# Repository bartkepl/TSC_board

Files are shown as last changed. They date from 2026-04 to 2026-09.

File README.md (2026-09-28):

# TSC (TimeStamp Counter)
TimeStamp Counter board, addon board to UCB_board 
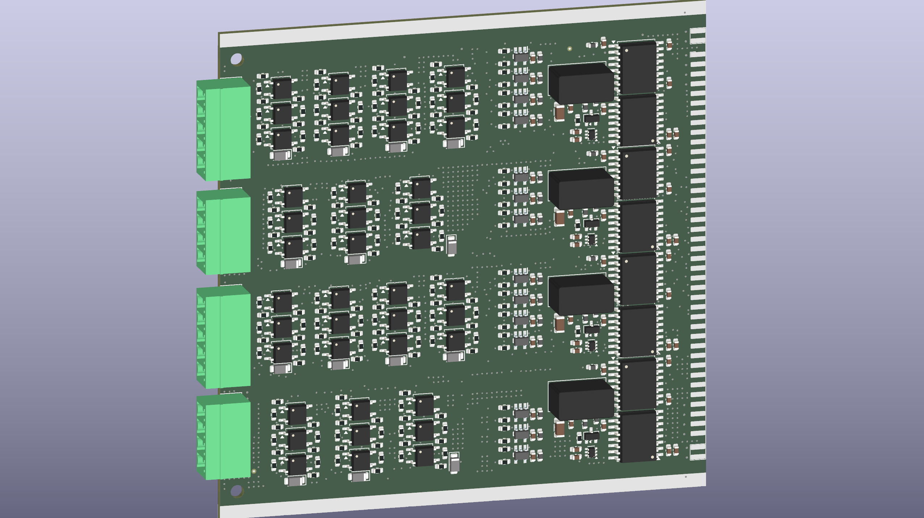
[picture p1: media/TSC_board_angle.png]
Time Stamp Counter board


| Top | Bottom |
|---|---|
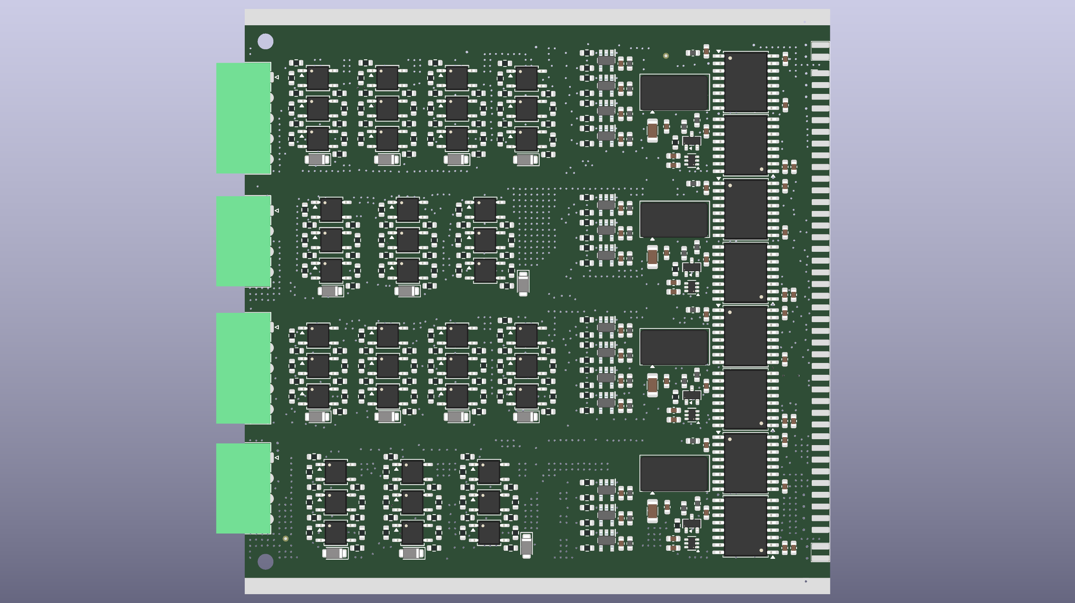
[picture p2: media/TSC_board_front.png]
Top
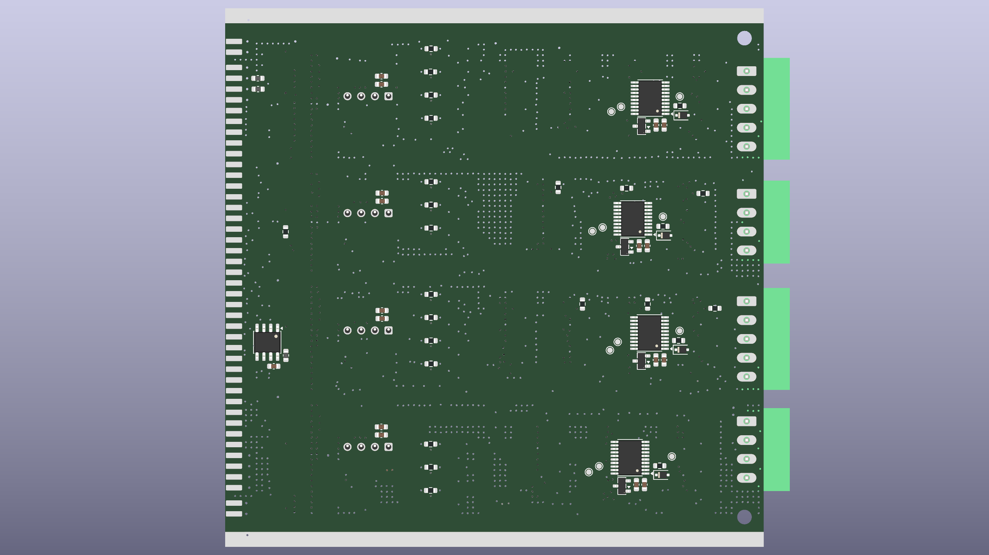
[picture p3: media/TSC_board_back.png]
Bottom
|  |  |

---
## Status: ready for prototype order

- Schematic and PCB layout done (4-layer, 100 × 100 mm), production files generated.
- Design review completed; DRC/ERC clean (remaining items reviewed and excluded as by-design).
- Hand assembly (2 fiducials on F.Cu for stencil alignment); LM4040 references (U15/U32/U46/U60) are DNP in this revision.

Production outputs: [schematic PDF](prod/sch/TSC_board.pdf) · [PCB PDF](prod/pcb/TSC_board.pdf) · [interactive BOM](prod/ibom/TSC_board_ibom.html) · [gerbers](prod/TSC_board.zip)

---

## Features (with UCB_board):
- 2x4 timestamp ports with 0-25v input range and isolation
- 2x3 isolated counter ports 
- Digital threshold level control
- USB 2.0
- 10/100 Ethernet (based on WIZnet W5500)
- UART
- Half-duplex RS485 
- 3U eurocard IEEE 1101.1-1998 format (160x100 mm) — this 100 × 100 mm front module is combined with the UCB_board backend

## License and Contribution

[MIT License](/LICENSE)

Open to contributions in both software and hardware!

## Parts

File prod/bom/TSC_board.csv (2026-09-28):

Oznaczenie | Wartość | Footprint | Opis | Liczba
C1,C4,C5,C6,C8,C9,C10,C11,C12,C13,C15,C17,C20,C21,C22,C24,C25,C26,C27,C28,C29,C31,C33,C36,C37,C38,C40,C41,C42,C43,C44,C46,C48,C51,C52,C53,C55,C56,C57,C58,C59,C61,C63,C64,C65,C66,C67,C68,C69,C70,C71 | 100n | Capacitor_SMD:C_0603_1608Metric | Unpolarized capacitor | 51
C2,C18,C34,C49 | 10u | Capacitor_SMD:C_1206_3216Metric | Unpolarized capacitor | 4
C3,C7,C14,C19,C23,C30,C35,C39,C45,C50,C54,C60 | 10n | Capacitor_SMD:C_0603_1608Metric | Unpolarized capacitor | 12
C16,C32,C47,C62 | 1n | Capacitor_SMD:C_0603_1608Metric | Unpolarized capacitor | 4
D1,D2,D3,D4,D5,D6,D7,D8,D9,D10,D11,D12,D13,D14 | SMF5.0CA | Diode_SMD:D_SMF |  | 14
D15,D16,D17,D18 | D | Diode_SMD:D_SOD-323F | Diode | 4
FB2,FB3,FB5,FB6,FB7,FB8,FB9,FB10,FB11,FB12,FB13,FB14,FB15,FB16,FB17,FB18,FB19,FB20,FB21,FB22,FB23,FB24,FB25,FB26,FB27,FB28,FB29,FB30,FB31 | 100R @ 100MHz | Inductor_SMD:L_0603_1608Metric |  | 29
IC1,IC2,IC3,IC4,IC5,IC6,IC7,IC8,IC9,IC10,IC11,IC12,IC13,IC14 | TS3021ILT | TS3021ILT:SOT95P280X145-5N | Rail-to-rail 1.8 V high-speed comparator | 14
IC15,IC16,IC17,IC18 | NCP51460SN33T1G | Package_TO_SOT_SMD:SOT-23 | Operating Input Voltage VIN 4.2 V to 28 V | Output Current Capability of 0 to 20 mA | Output Voltage Temperature Coefficient of 18 ppm/C | Output Voltage Accuracy 1 %, for 0 C TA 100 C | High PSRR of 68 dB at 1 kHz | Stable Without Output Capacitor | Low Quiescent Current of 140 A | Low Output Noise of 18 VRMS | Output Voltage Option: 3.3V | 4
J1,J2 | Conn_01x05_Socket | Connector_Phoenix_MC:PhoenixContact_MC_1,5_5-G-3.5_1x05_P3.50mm_Horizontal | Generic connector, single row, 01x05, script generated | 2
J3,J4 | Conn_01x04_Socket | Connector_Phoenix_MC:PhoenixContact_MC_1,5_4-G-3.5_1x04_P3.50mm_Horizontal | Generic connector, single row, 01x04, script generated | 2
R1,R12,R31,R50,R58,R69,R88,R107,R115,R124,R139,R158,R167,R182 | 50k | Resistor_SMD:R_0603_1608Metric | Resistor | 14
R2,R17,R39,R51,R59,R74,R96,R108,R116,R128,R145,R159,R171,R188 | 1k | Resistor_SMD:R_0603_1608Metric | Resistor | 14
R3,R18,R45,R52,R60,R75,R102,R109,R117,R129,R150,R160,R172,R193 | 100 | Resistor_SMD:R_0603_1608Metric | Resistor | 14
R4,R5,R6,R7,R19,R20,R21,R22,R36,R37,R38,R40,R61,R62,R63,R64,R76,R77,R78,R79,R93,R94,R95,R97,R118,R119,R120,R130,R131,R132,R143,R144,R146,R161,R162,R163,R173,R174,R175,R186,R187,R189 | 470 | Resistor_SMD:R_0603_1608Metric | Resistor | 42
R8,R9,R10,R11,R13,R14,R15,R16,R23,R24,R25,R26,R27,R28,R29,R30,R32,R33,R34,R35,R41,R42,R43,R44,R46,R47,R48,R49,R53,R54,R55,R56,R65,R66,R67,R68,R70,R71,R72,R73,R80,R81,R82,R83,R84,R85,R86,R87,R89,R90,R91,R92,R98,R99,R100,R101,R103,R104,R105,R106,R110,R111,R112,R113,R121,R122,R123,R125,R126,R127,R133,R134,R135,R136,R137,R138,R140,R141,R142,R147,R148,R149,R151,R152,R153,R154,R155,R156,R164,R165,R166,R168,R169,R170,R176,R177,R178,R179,R180,R181,R183,R184,R185,R190,R191,R192,R194,R195,R196,R197,R198,R199,R201,R202,R203,R204,R205 | 10k | Resistor_SMD:R_0603_1608Metric | Resistor | 117
R57,R114,R157,R200 | 330 | Resistor_SMD:R_0603_1608Metric | Resistor | 4
U1,U18,U35,U49 | TEA1-0505 | Converter_DCDC:Converter_DCDC_TRACO_TEA1-xxxx_THT | 1W DC/DC converter unregulated, 4.5-5.5V input, 5V output voltage, 200mA output, 1.5kVDC isolation, SIP-4 | 4
U2,U3,U4,U5,U6,U7,U8,U9,U11,U12,U13,U14,U19,U20,U21,U22,U23,U24,U25,U26,U28,U29,U30,U31,U36,U37,U38,U39,U40,U41,U43,U44,U45,U50,U51,U52,U53,U54,U55,U57,U58,U59 | GAQY212GS | Package_SO:SOP-4_3.8x4.1mm_P2.54mm | Form A, Solid State Relay (Photo MOSFET) 60V, 0.08A, 0,24Ohm, AC/DC, SO-4 | 42
U10,U27 | ADuM1400BRWZ | Package_SO:SOIC-16W_7.5x10.3mm_P1.27mm | Quad Channel Digital Isolator, 10Mbps, SOIC-16 | 2
U15,U32,U46,U60 | LM4040D33FTA | Package_TO_SOT_SMD:SOT-23 | 3.300V Precision Micropower Shunt Voltage Reference, SOT-23 | 4
U16,U33,U47,U61 | DAC7311IDCKR | Package_TO_SOT_SMD:SOT-363_SC-70-6 | 12-Bit, Single-Channel, Voltage Output, Serial Interface Digital-to-Analog Converters, SC-70 | 4
U17,U34,U42,U48,U56,U62 | ADuM1300BRWZ | Package_SO:SOIC-16W_7.5x10.3mm_P1.27mm | Three Channel Digital Isolator, 10Mbps, SOICW-16 | 6
U63 | APS6404L-3SQR-SN | Package_SO:SOIC-8_3.9x4.9mm_P1.27mm | 64 Mbit / 8M x 8-bits serial pseudo SRAM MEMORY, up to 133MHz, 2.7-3.6V supply, SOIC-8 (SOP-8) | 1
U64,U65,U66,U67 | STM32C011F4P6 | Package_SO:TSSOP-20_4.4x6.5mm_P0.65mm | STMicroelectronics Arm Cortex-M0+ MCU, 16KB flash, 6KB RAM, 48 MHz, 2.0-3.6V, 18 GPIO, TSSOP20 | 4

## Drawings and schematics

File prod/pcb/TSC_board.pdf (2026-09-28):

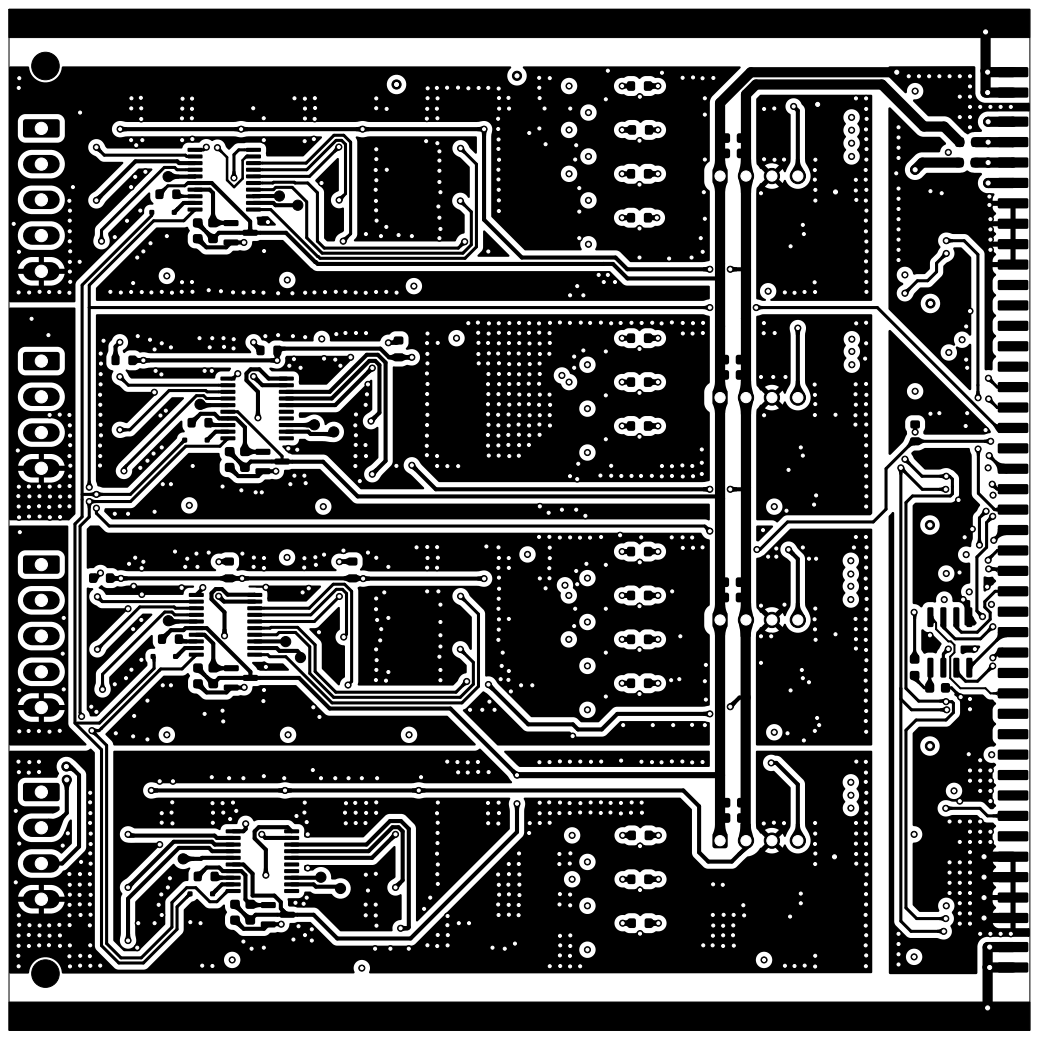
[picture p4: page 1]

Size: A4 | Rev: 0.1
KiCad E.D.A. 10.0.4 | Id: 1/6

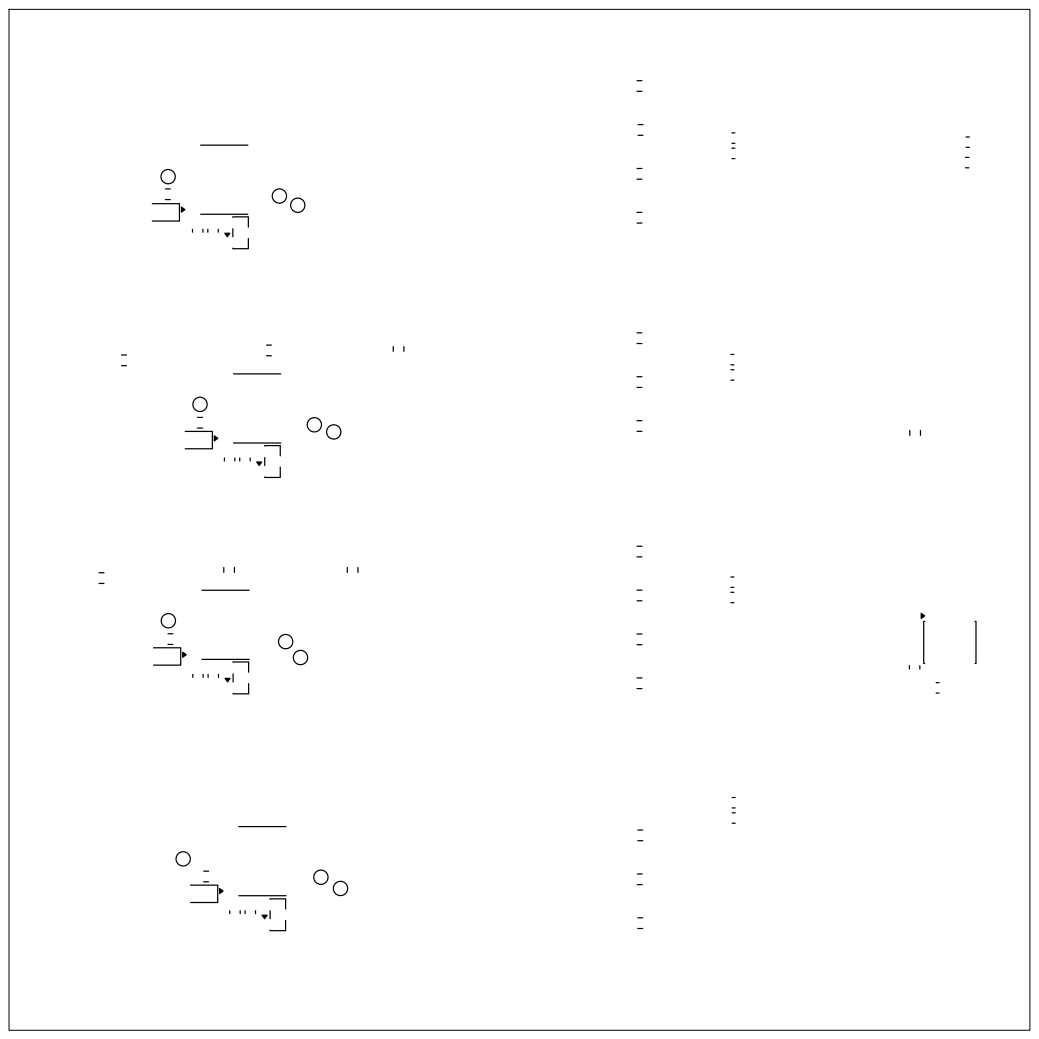
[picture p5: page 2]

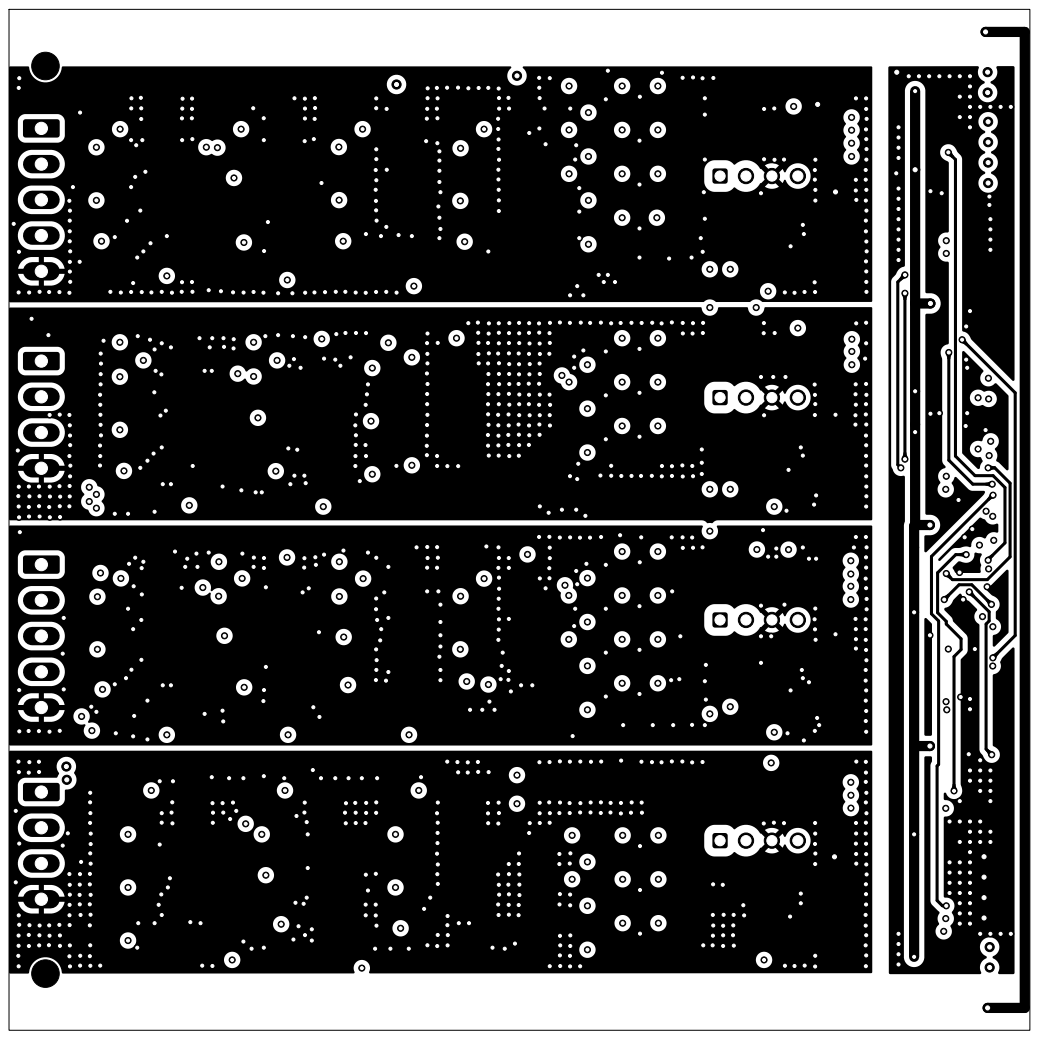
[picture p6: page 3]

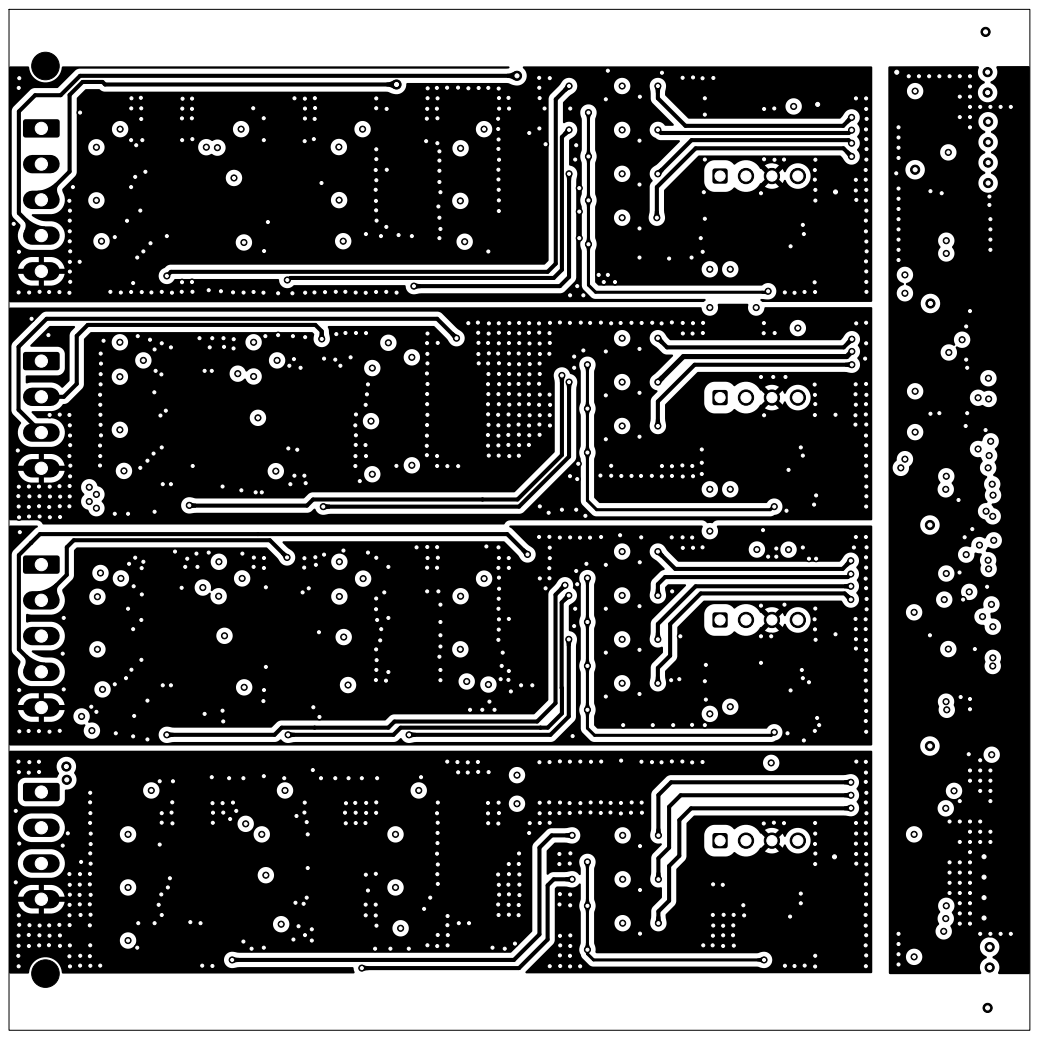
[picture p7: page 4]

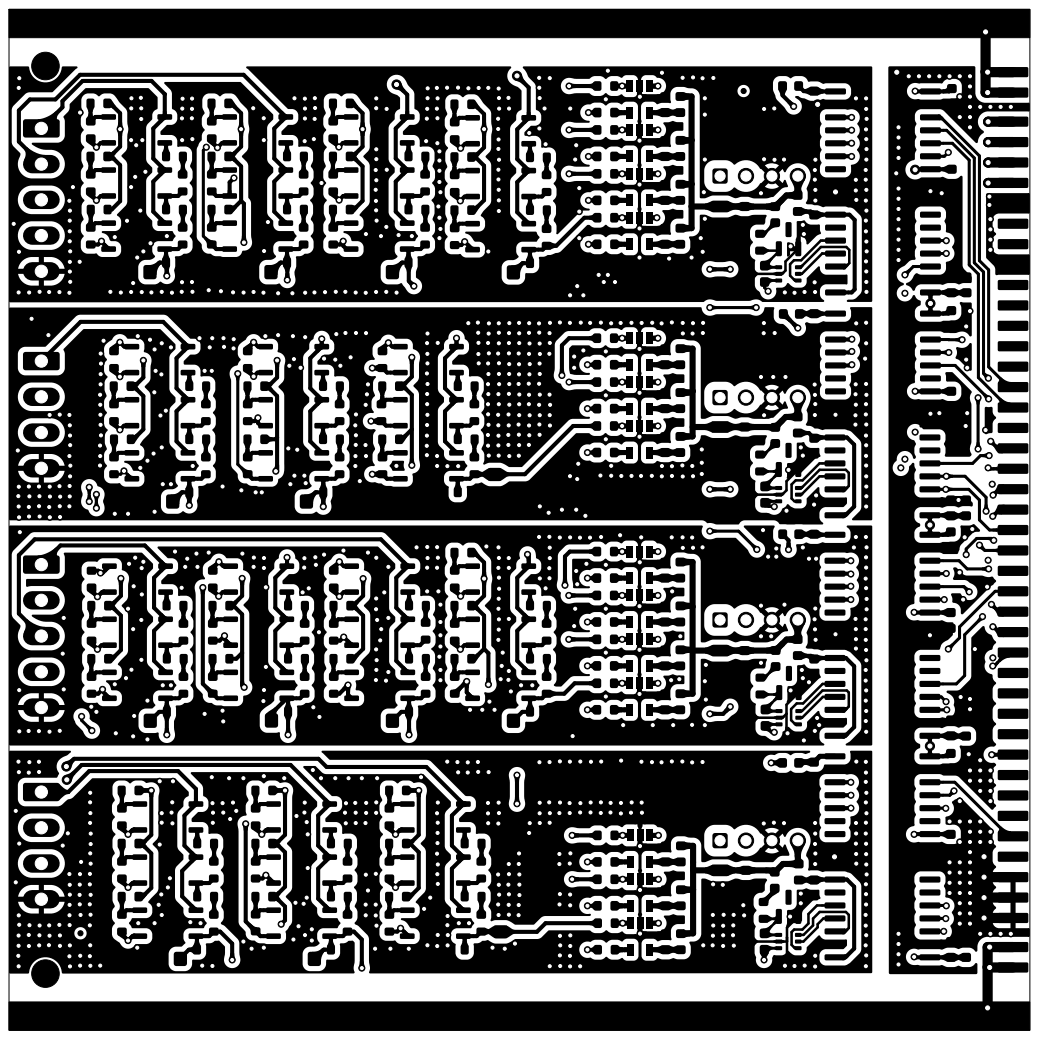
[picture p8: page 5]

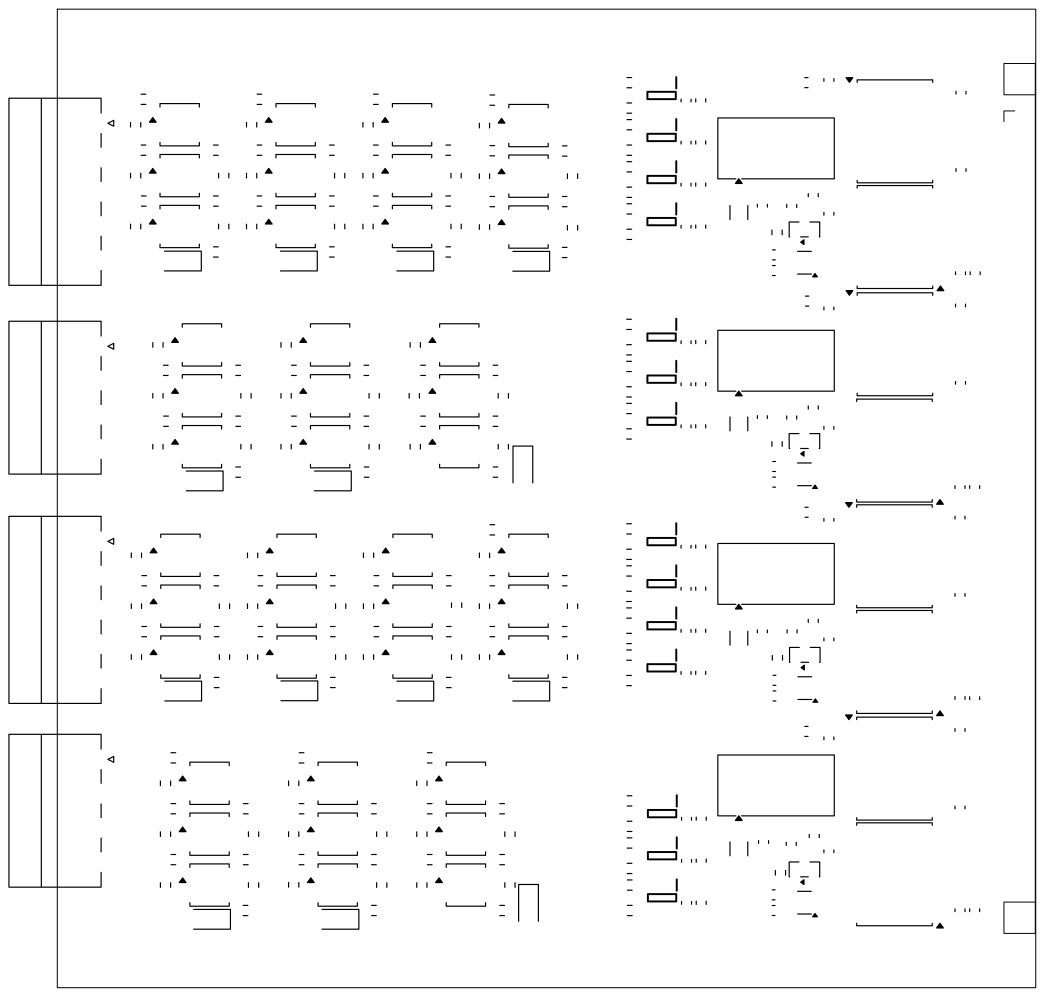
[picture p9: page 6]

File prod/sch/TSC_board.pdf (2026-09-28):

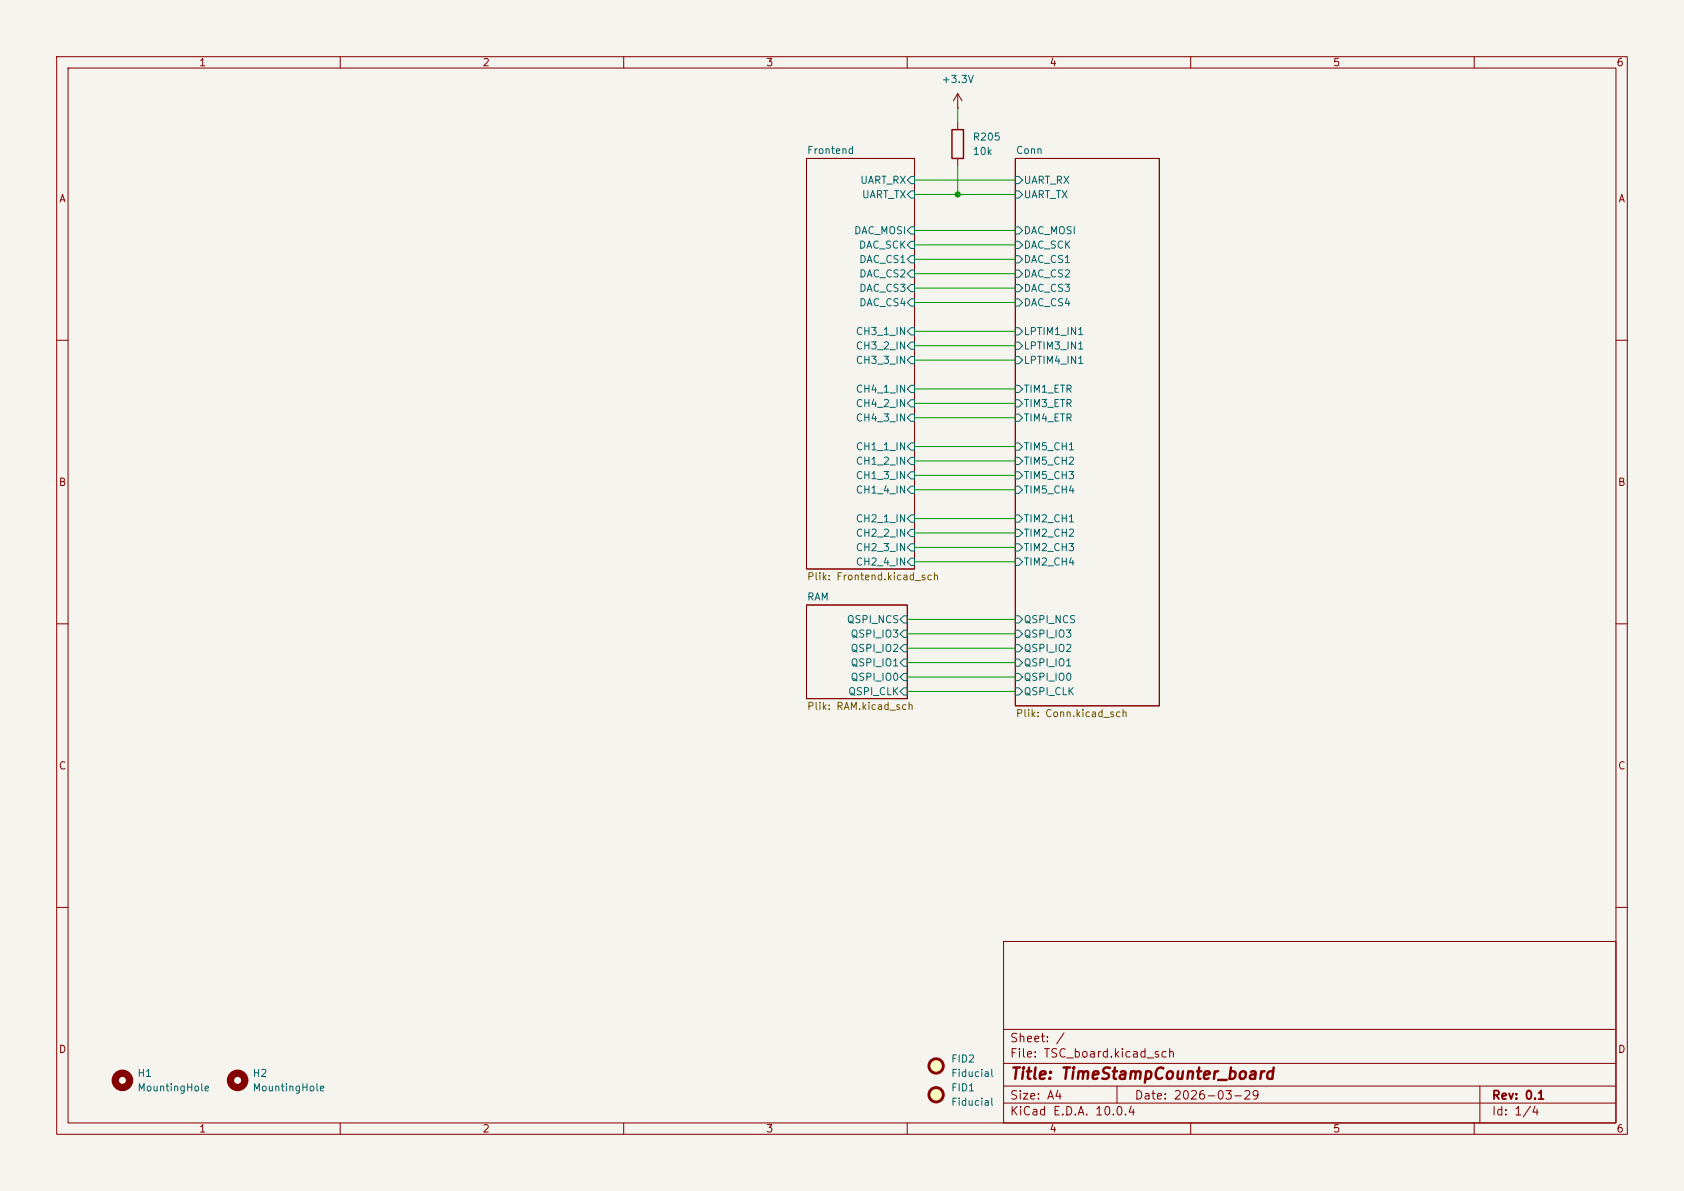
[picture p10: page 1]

Size: A4 | Rev: 0.1
KiCad E.D.A. 10.0.4 | Id: 1/4

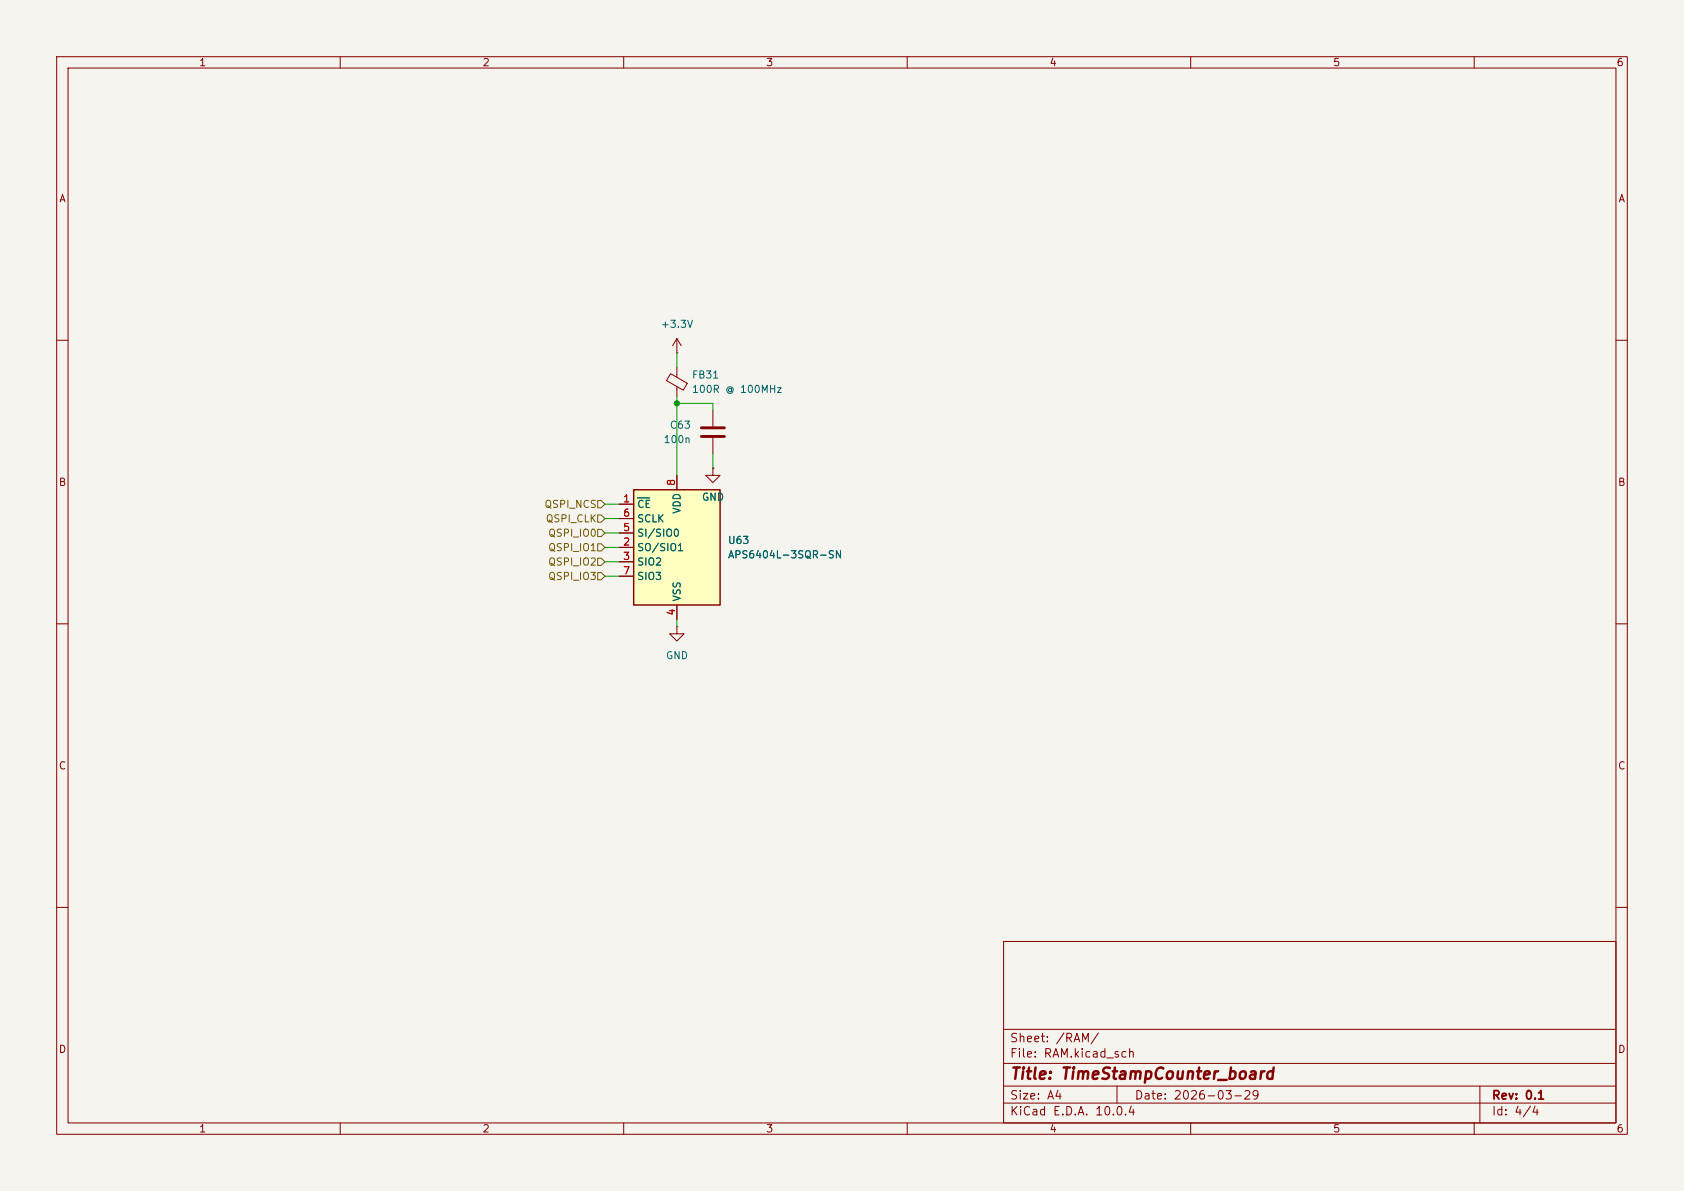
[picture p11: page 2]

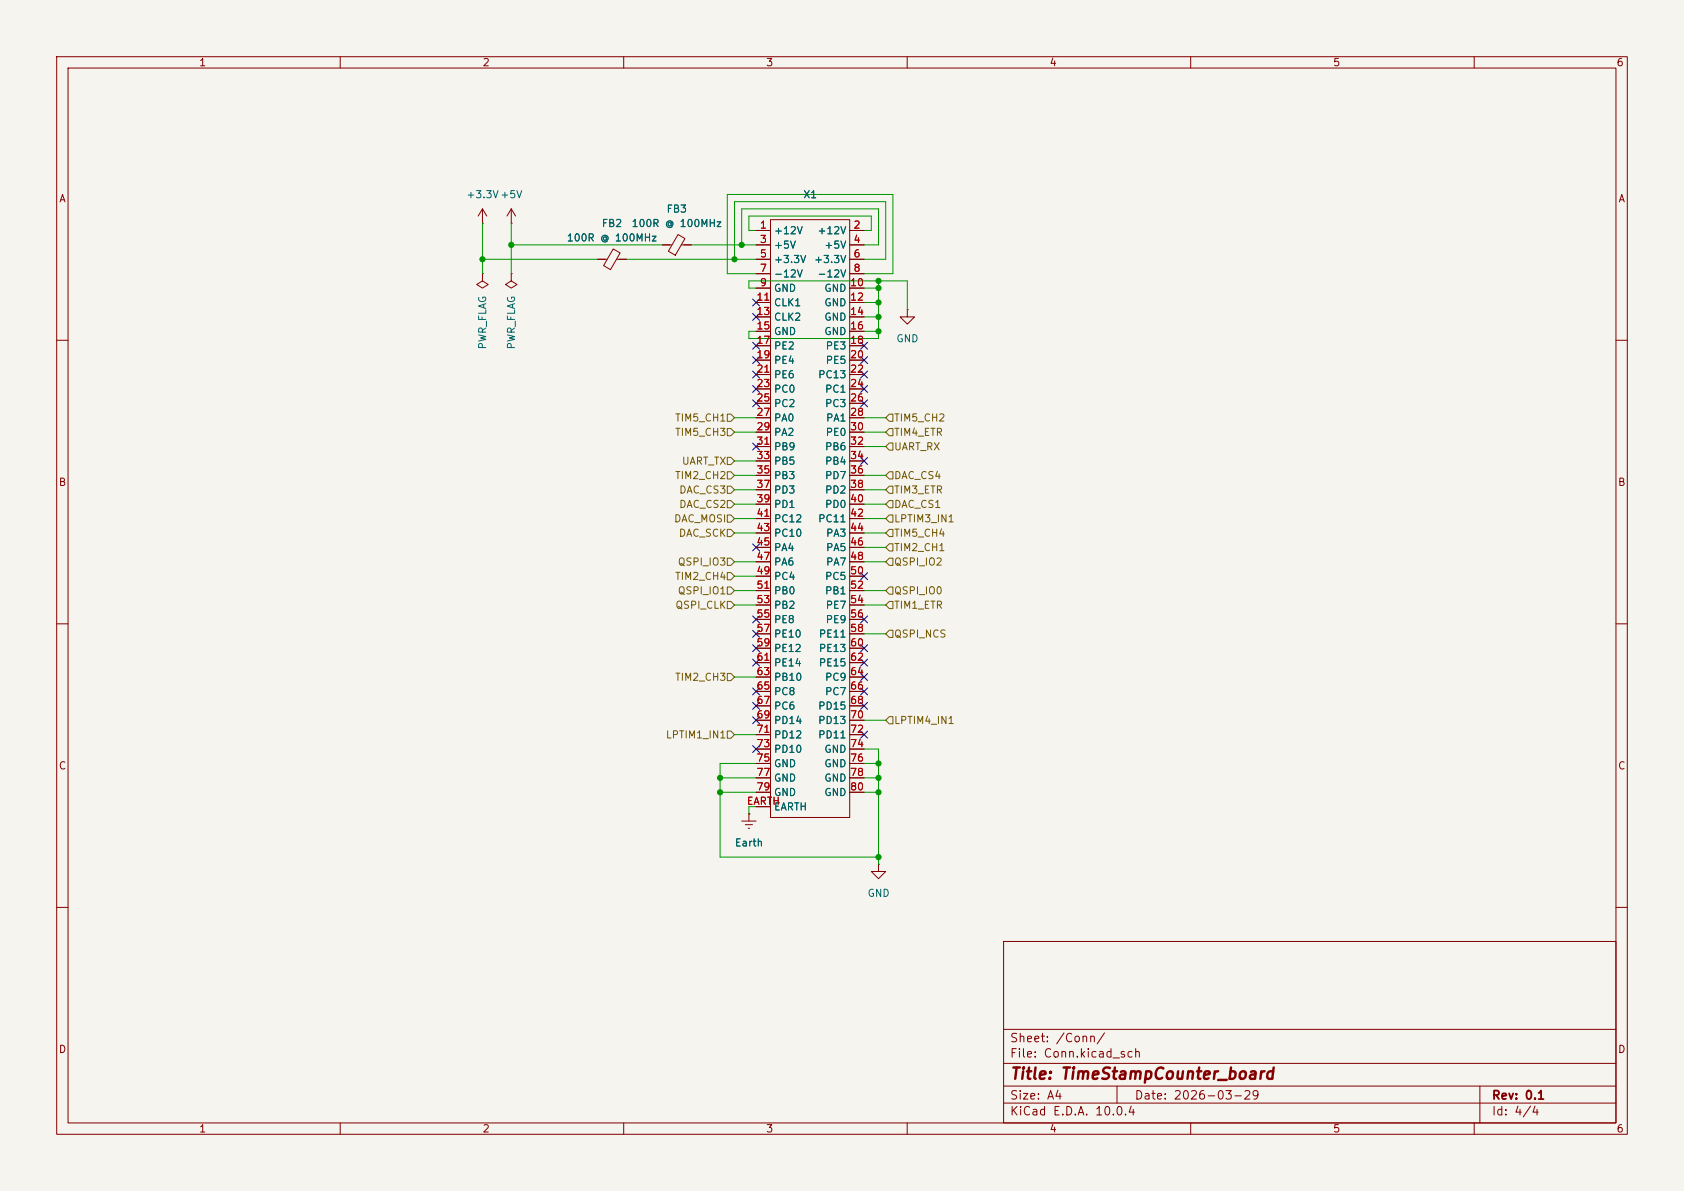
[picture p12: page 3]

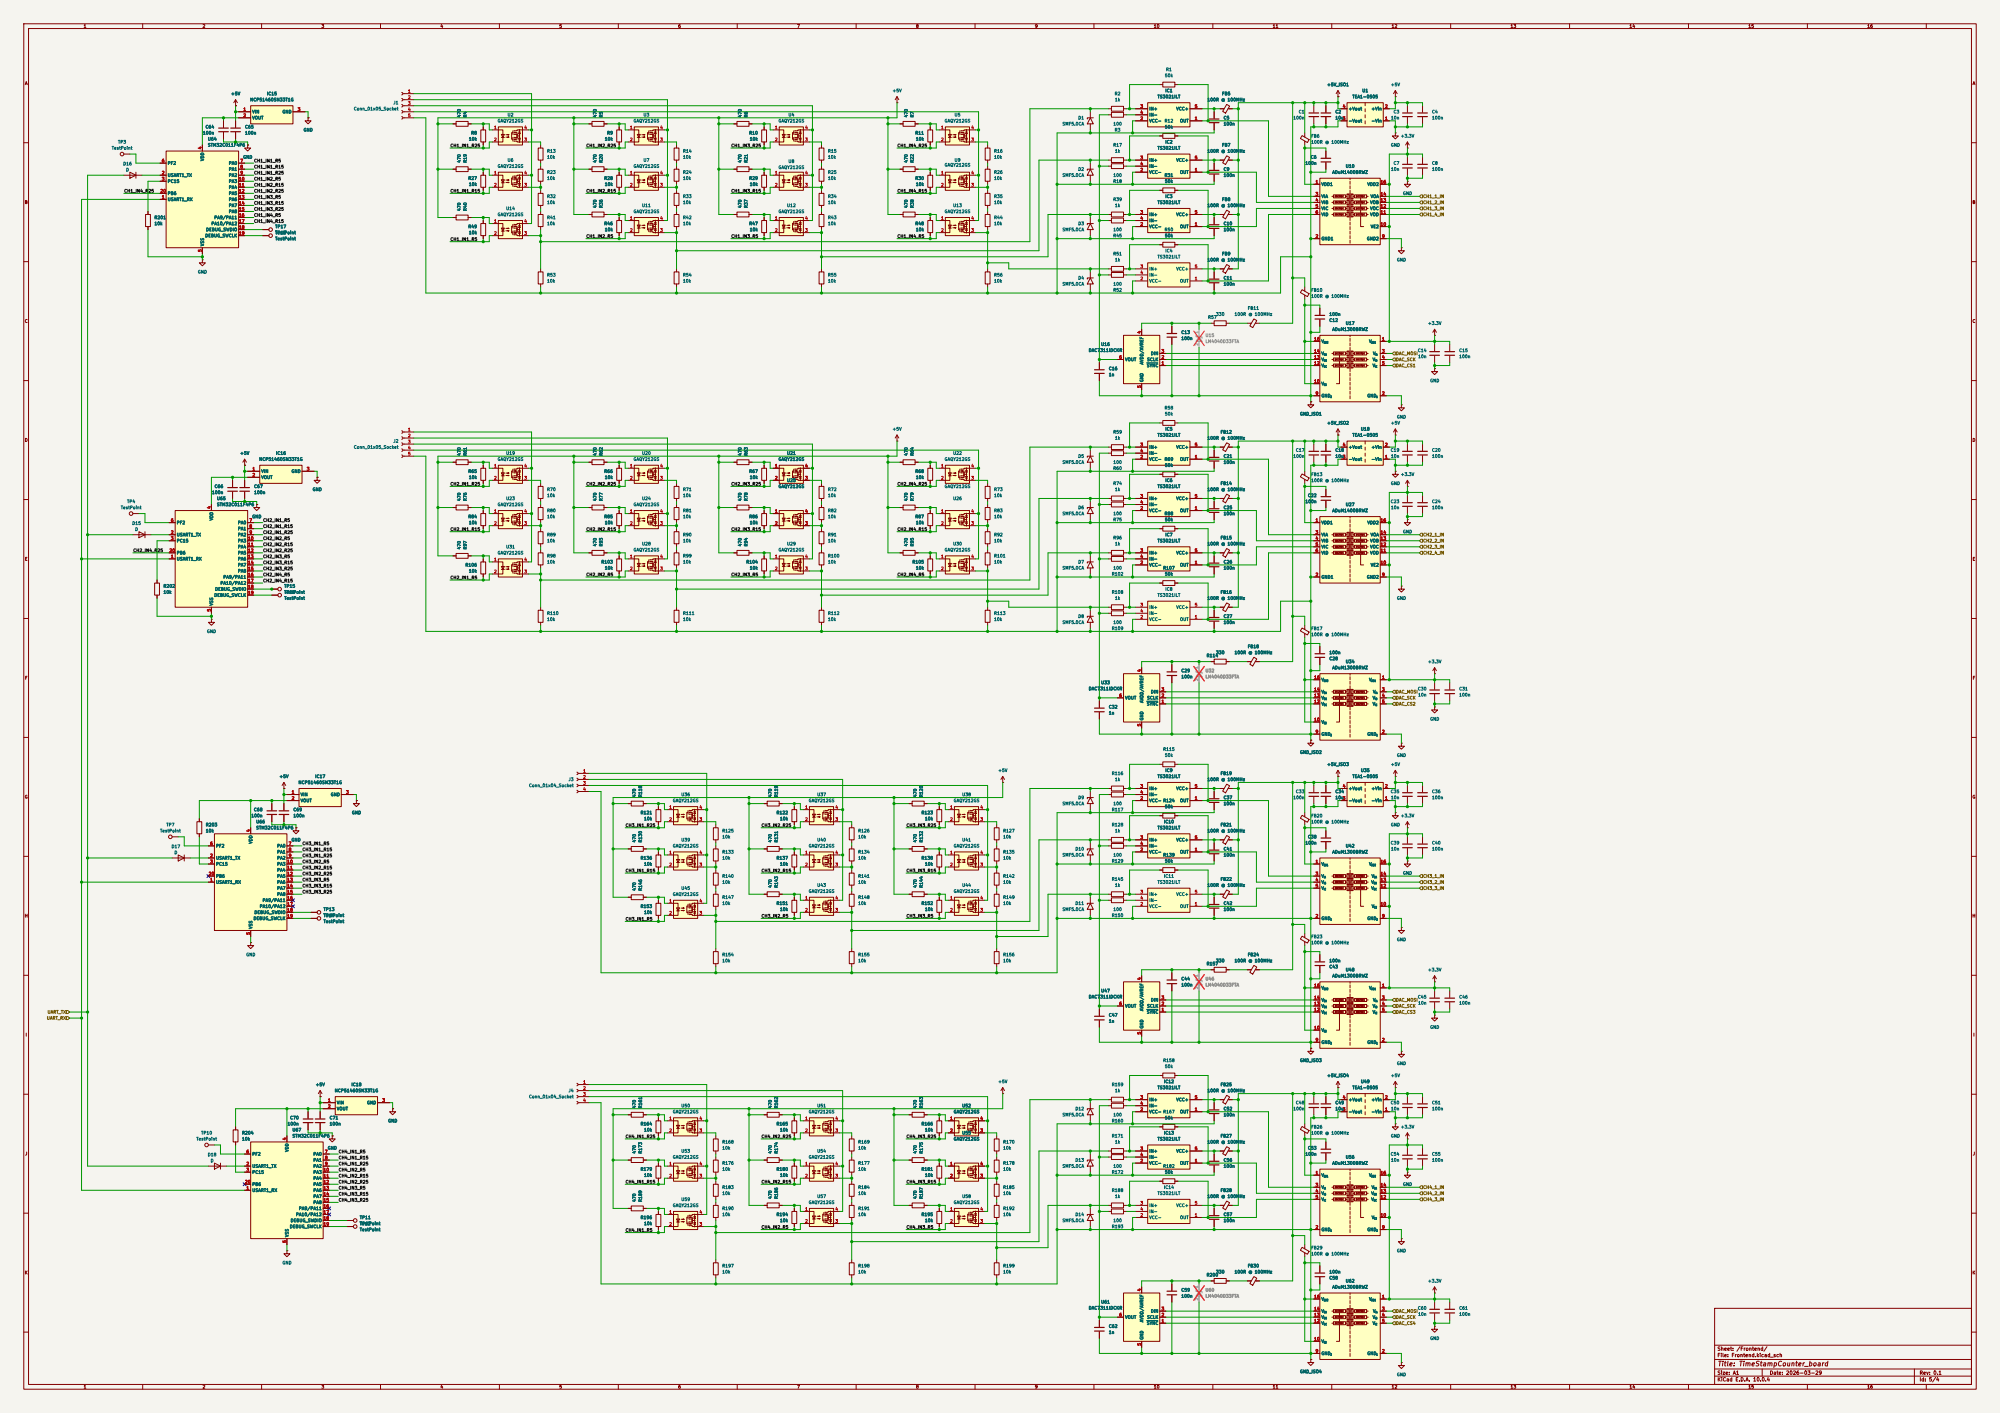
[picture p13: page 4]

ENCODE VIC 5 VIC 5

SMF5.0CA D10

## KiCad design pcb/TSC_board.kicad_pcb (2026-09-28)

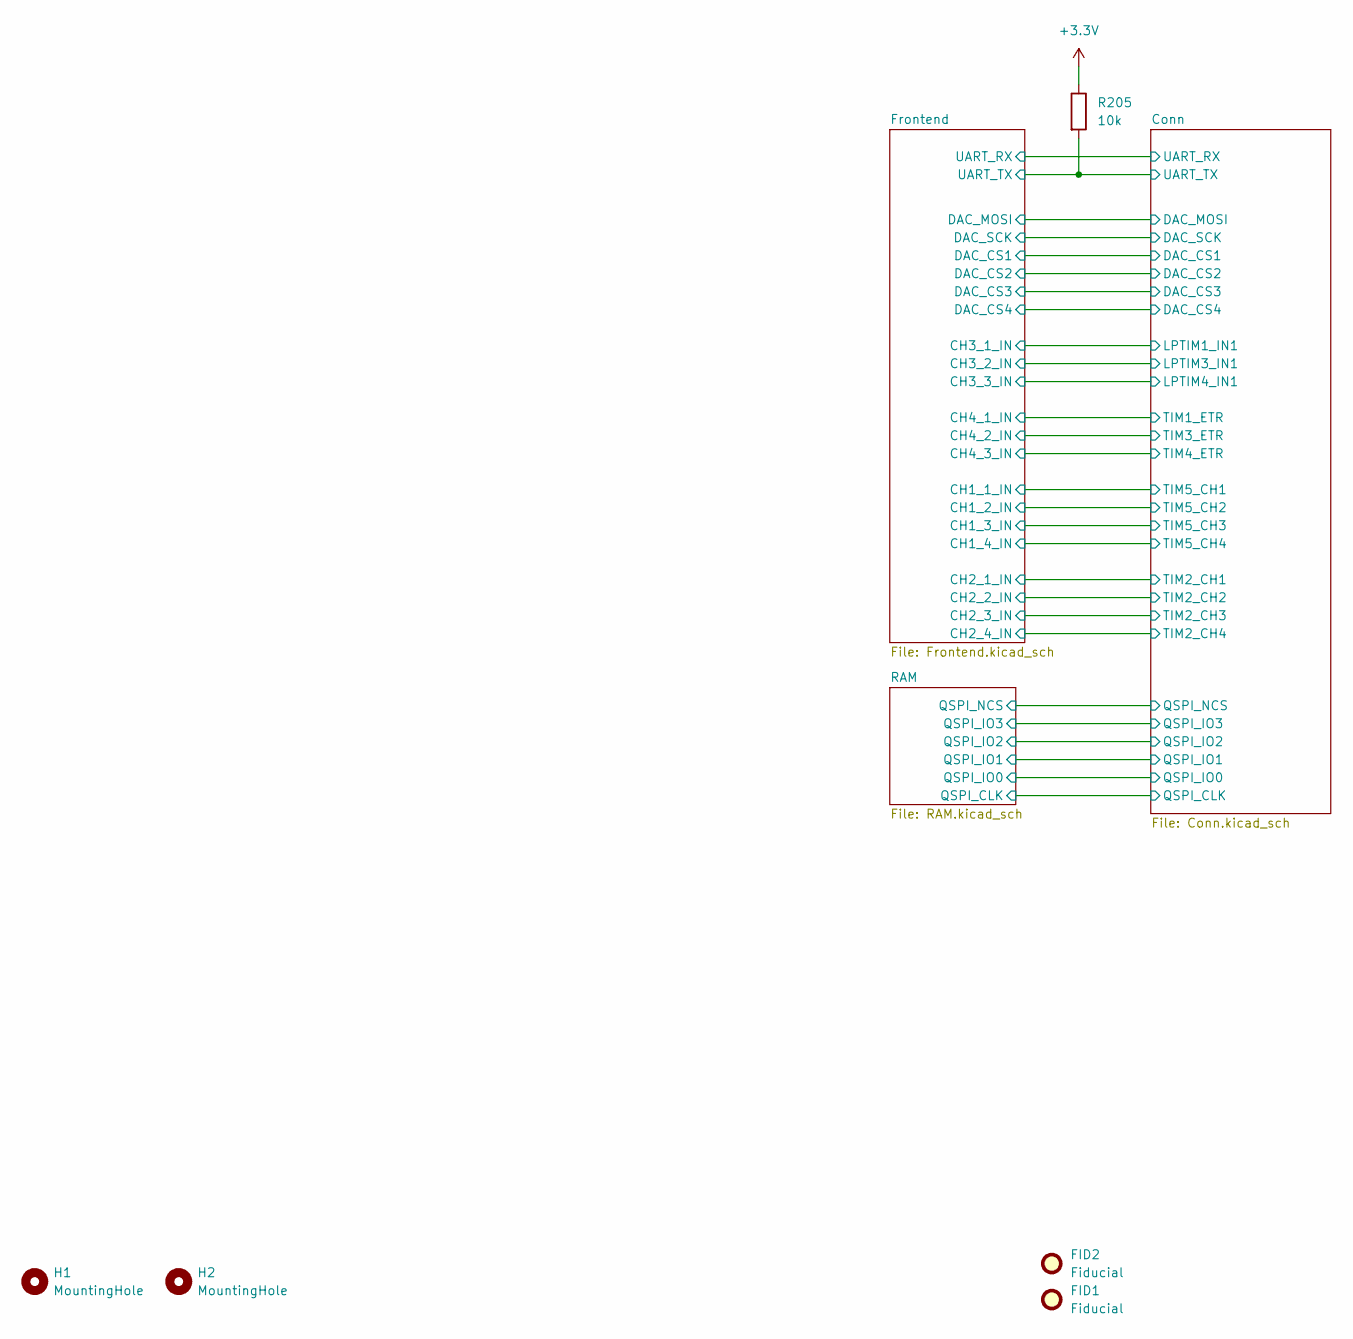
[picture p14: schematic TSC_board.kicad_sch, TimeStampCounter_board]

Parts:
FID1, FID2: Fiducial; Fiducial_0.5mm_Mask1mm
H1, H2: MountingHole; MountingHole_2.7mm_M2.5
R205: 10k; R_0603_1608Metric; Manufacturer_Part_Number CRCW060310K0FKTABC

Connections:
+3.3V: R205.1; also elsewhere on the board
/Conn/UART_TX: R205.2; also elsewhere on the board

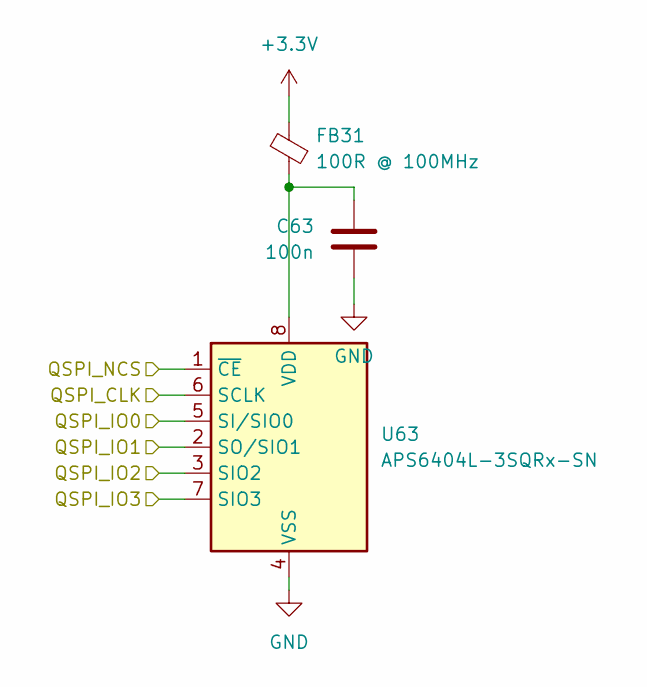
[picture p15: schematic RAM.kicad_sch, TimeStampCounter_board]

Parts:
C63: 100n; C_0603_1608Metric; Manufacturer_Part_Number GRM188R71H104KA93D
FB31: 100R @ 100MHz; L_0603_1608Metric; Manufacturer_Part_Number WLBD1608HCU101TL
U63: APS6404L-3SQRx-SN; SOIC-8_3.9x4.9mm_P1.27mm; Manufacturer_Part_Number APS6404L-3SQR

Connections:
+3.3V: FB31.2; also elsewhere on the board
/Conn/QSPI_CLK: U63.6 (SCLK); also elsewhere on the board
/Conn/QSPI_IO0: U63.5 (SI/SIO0); also elsewhere on the board
/Conn/QSPI_IO1: U63.2 (SO/SIO1); also elsewhere on the board
/Conn/QSPI_IO2: U63.3 (SIO2); also elsewhere on the board
/Conn/QSPI_IO3: U63.7 (SIO3); also elsewhere on the board
/Conn/QSPI_NCS: U63.1 (~CE); also elsewhere on the board
GND: C63.1, U63.4 (VSS); also elsewhere on the board
unnamed: C63.2, FB31.1, U63.8 (VDD)

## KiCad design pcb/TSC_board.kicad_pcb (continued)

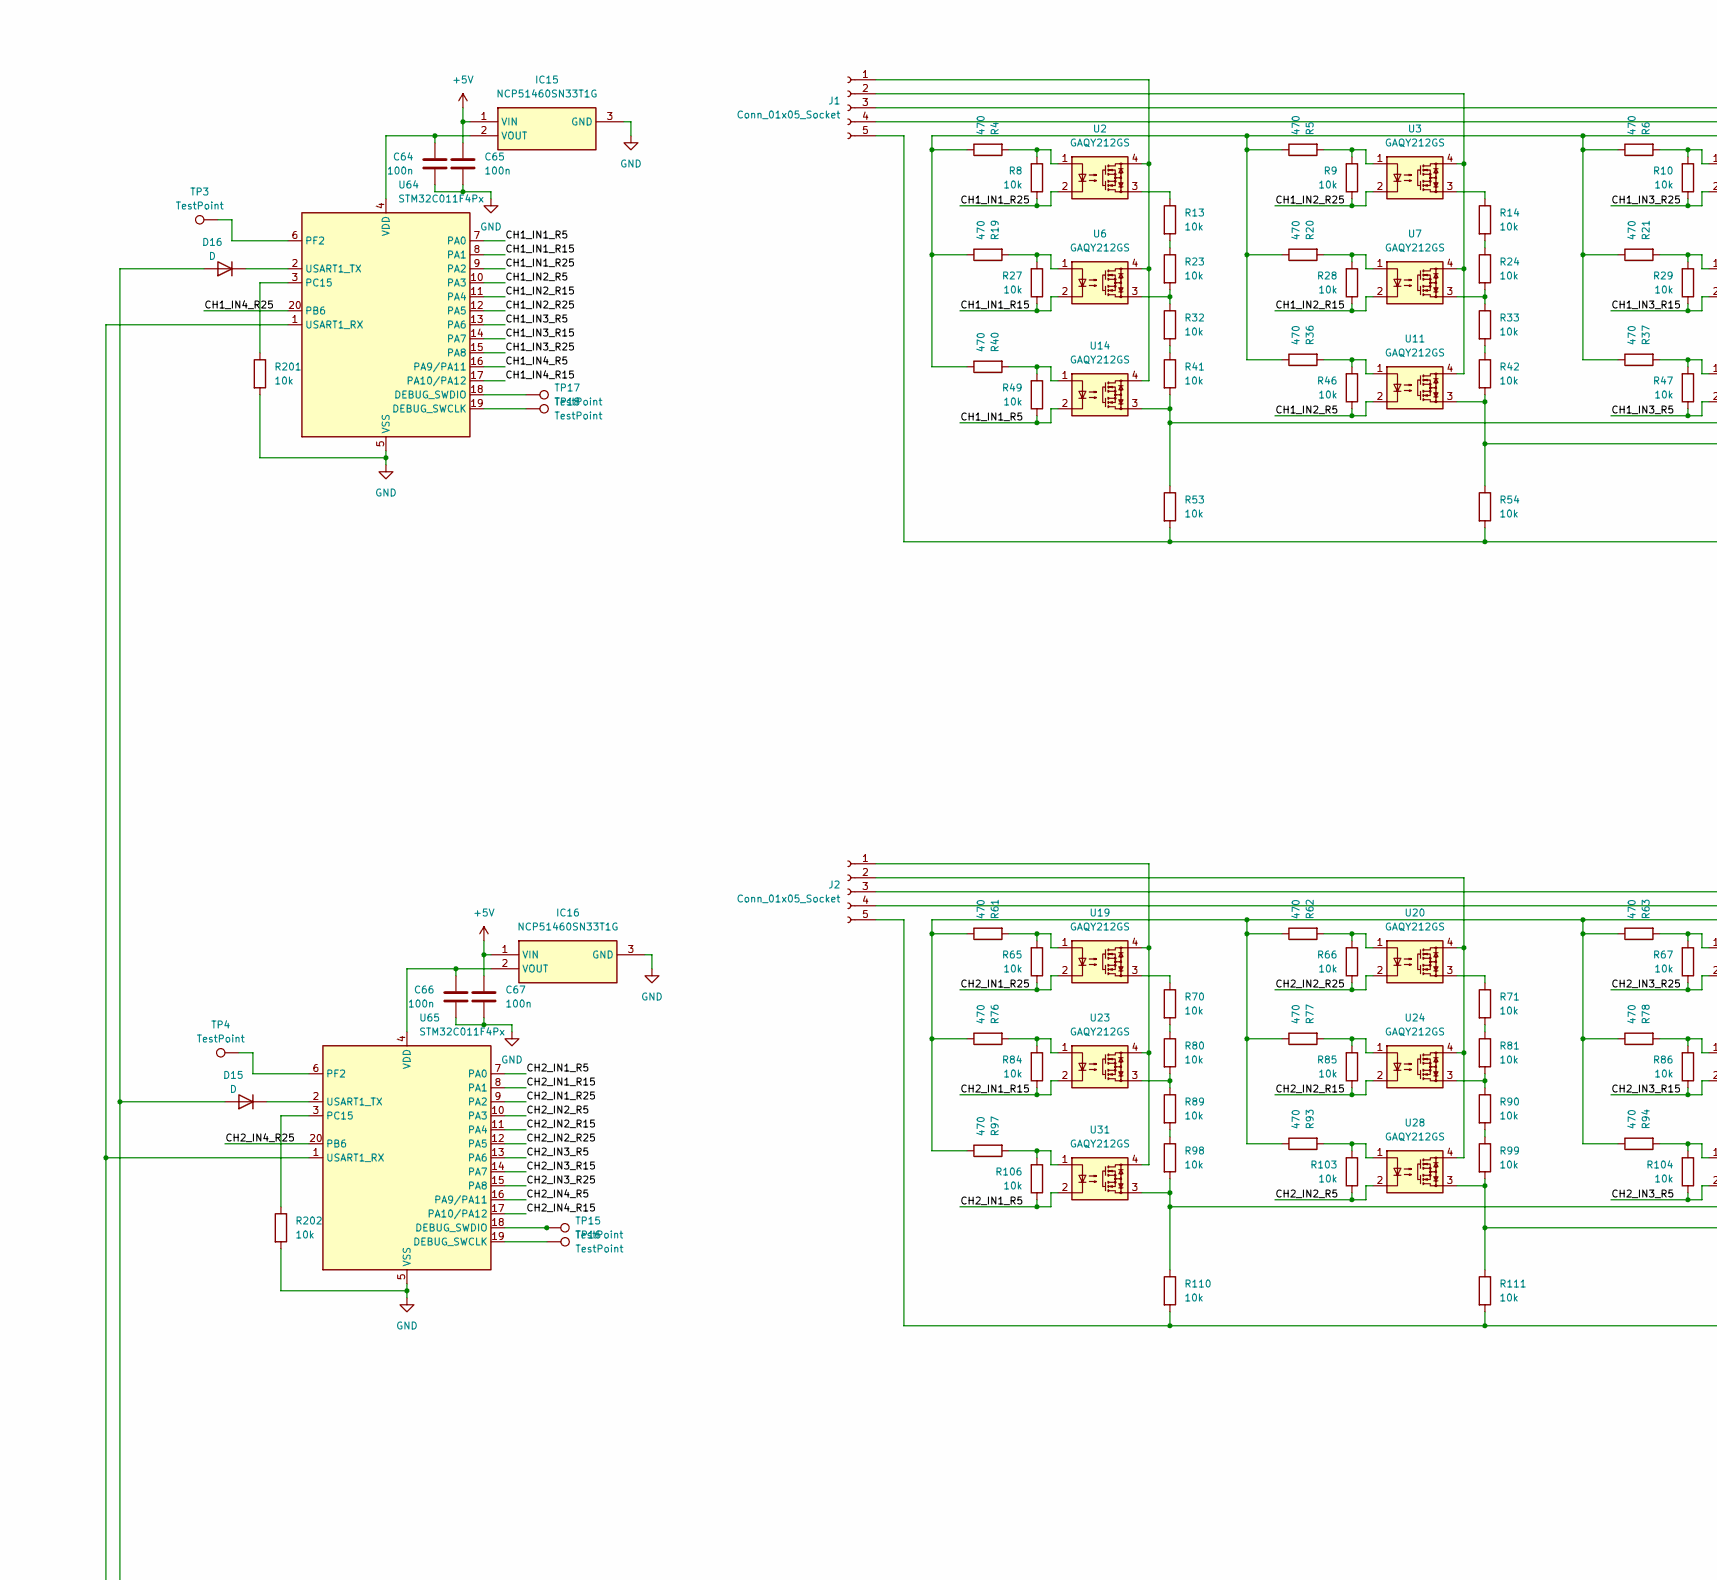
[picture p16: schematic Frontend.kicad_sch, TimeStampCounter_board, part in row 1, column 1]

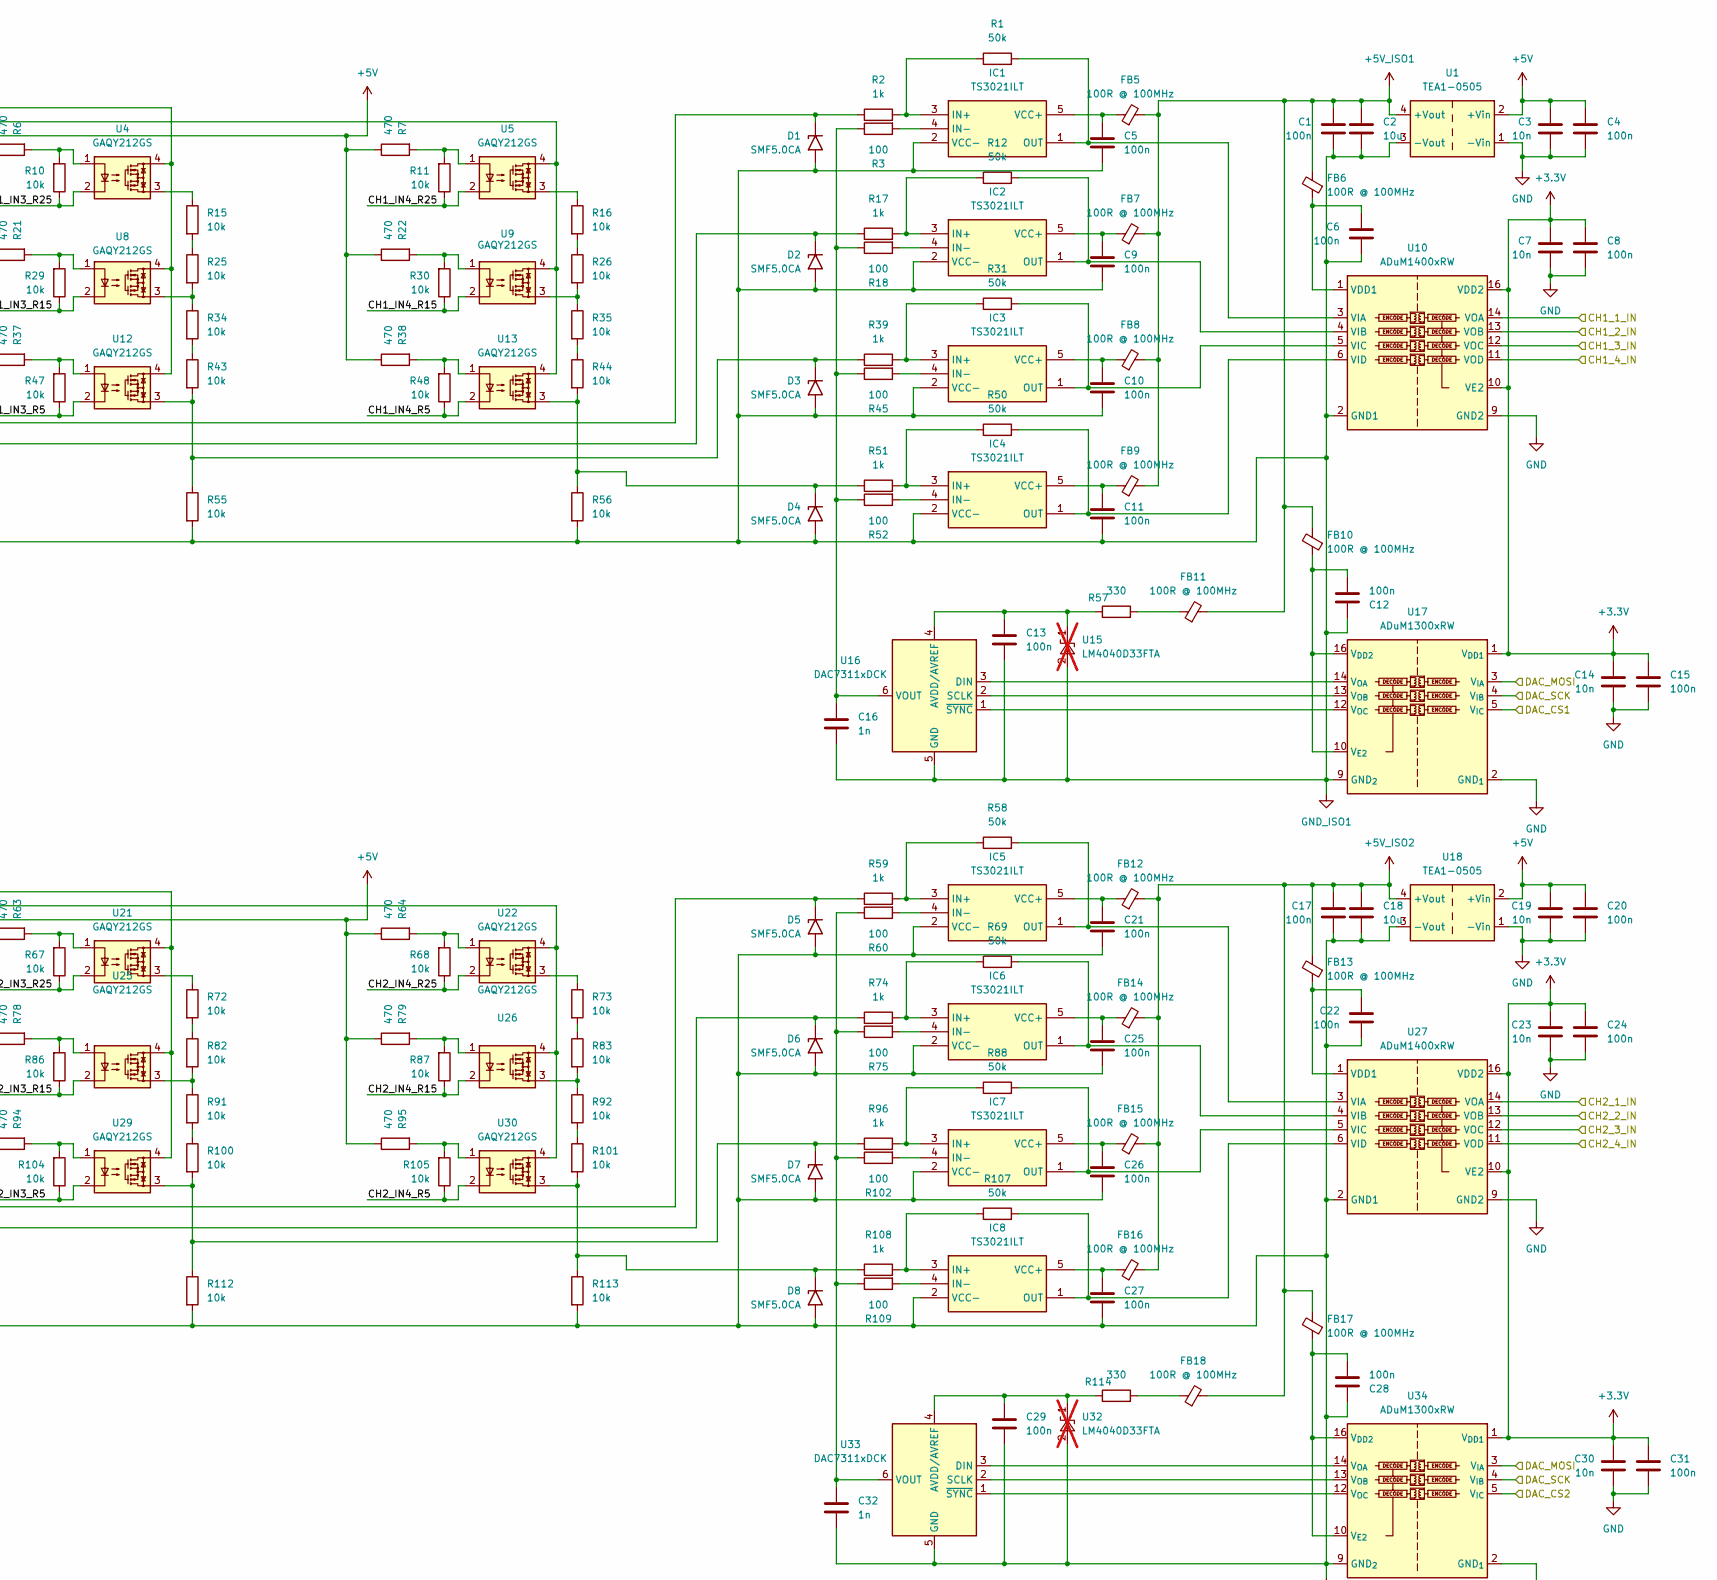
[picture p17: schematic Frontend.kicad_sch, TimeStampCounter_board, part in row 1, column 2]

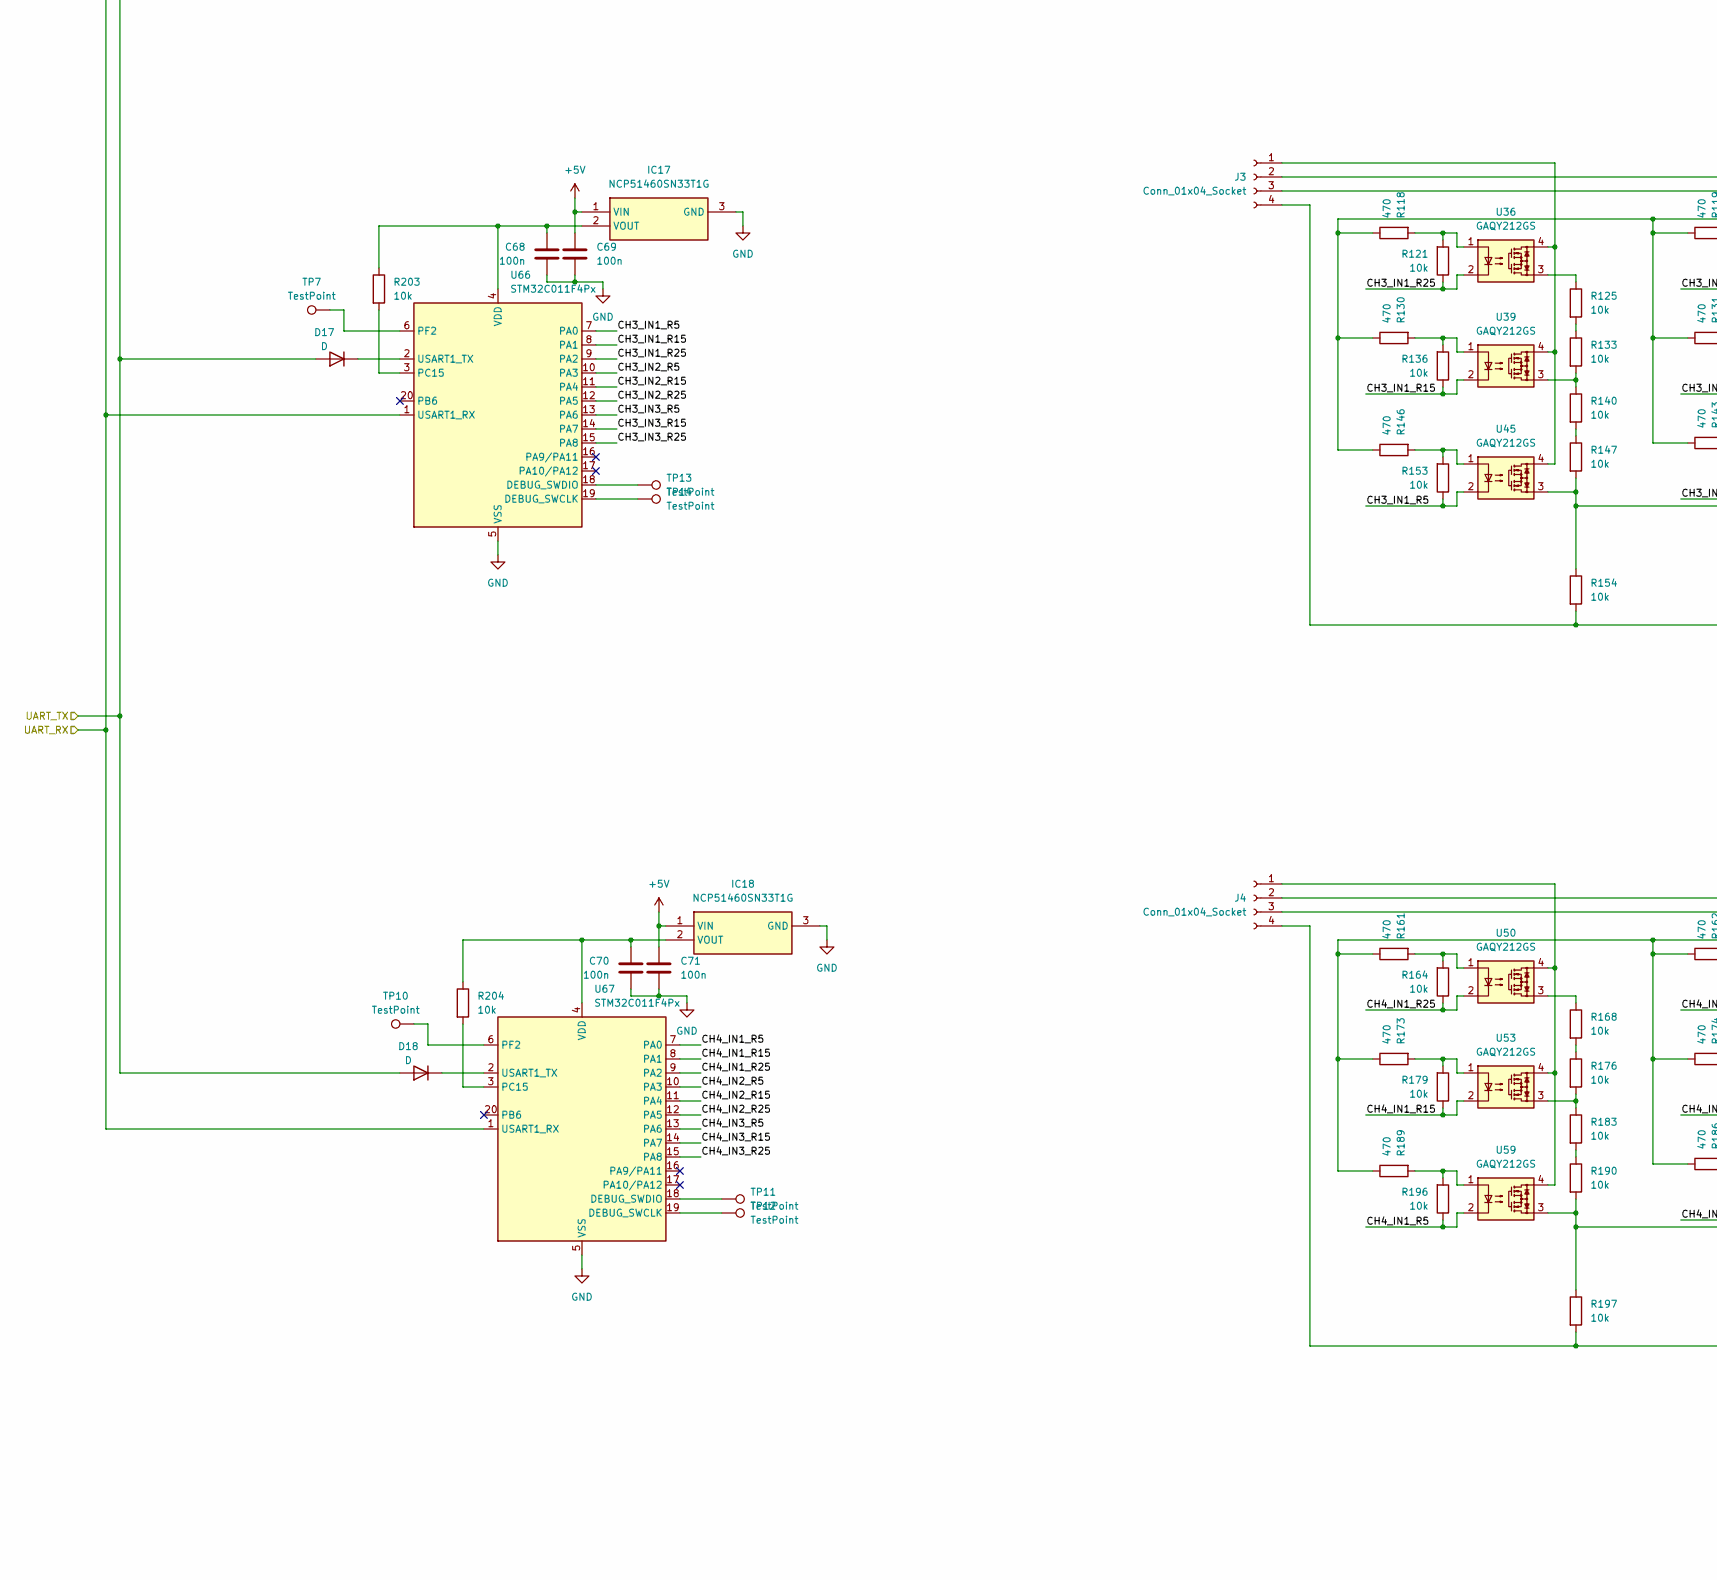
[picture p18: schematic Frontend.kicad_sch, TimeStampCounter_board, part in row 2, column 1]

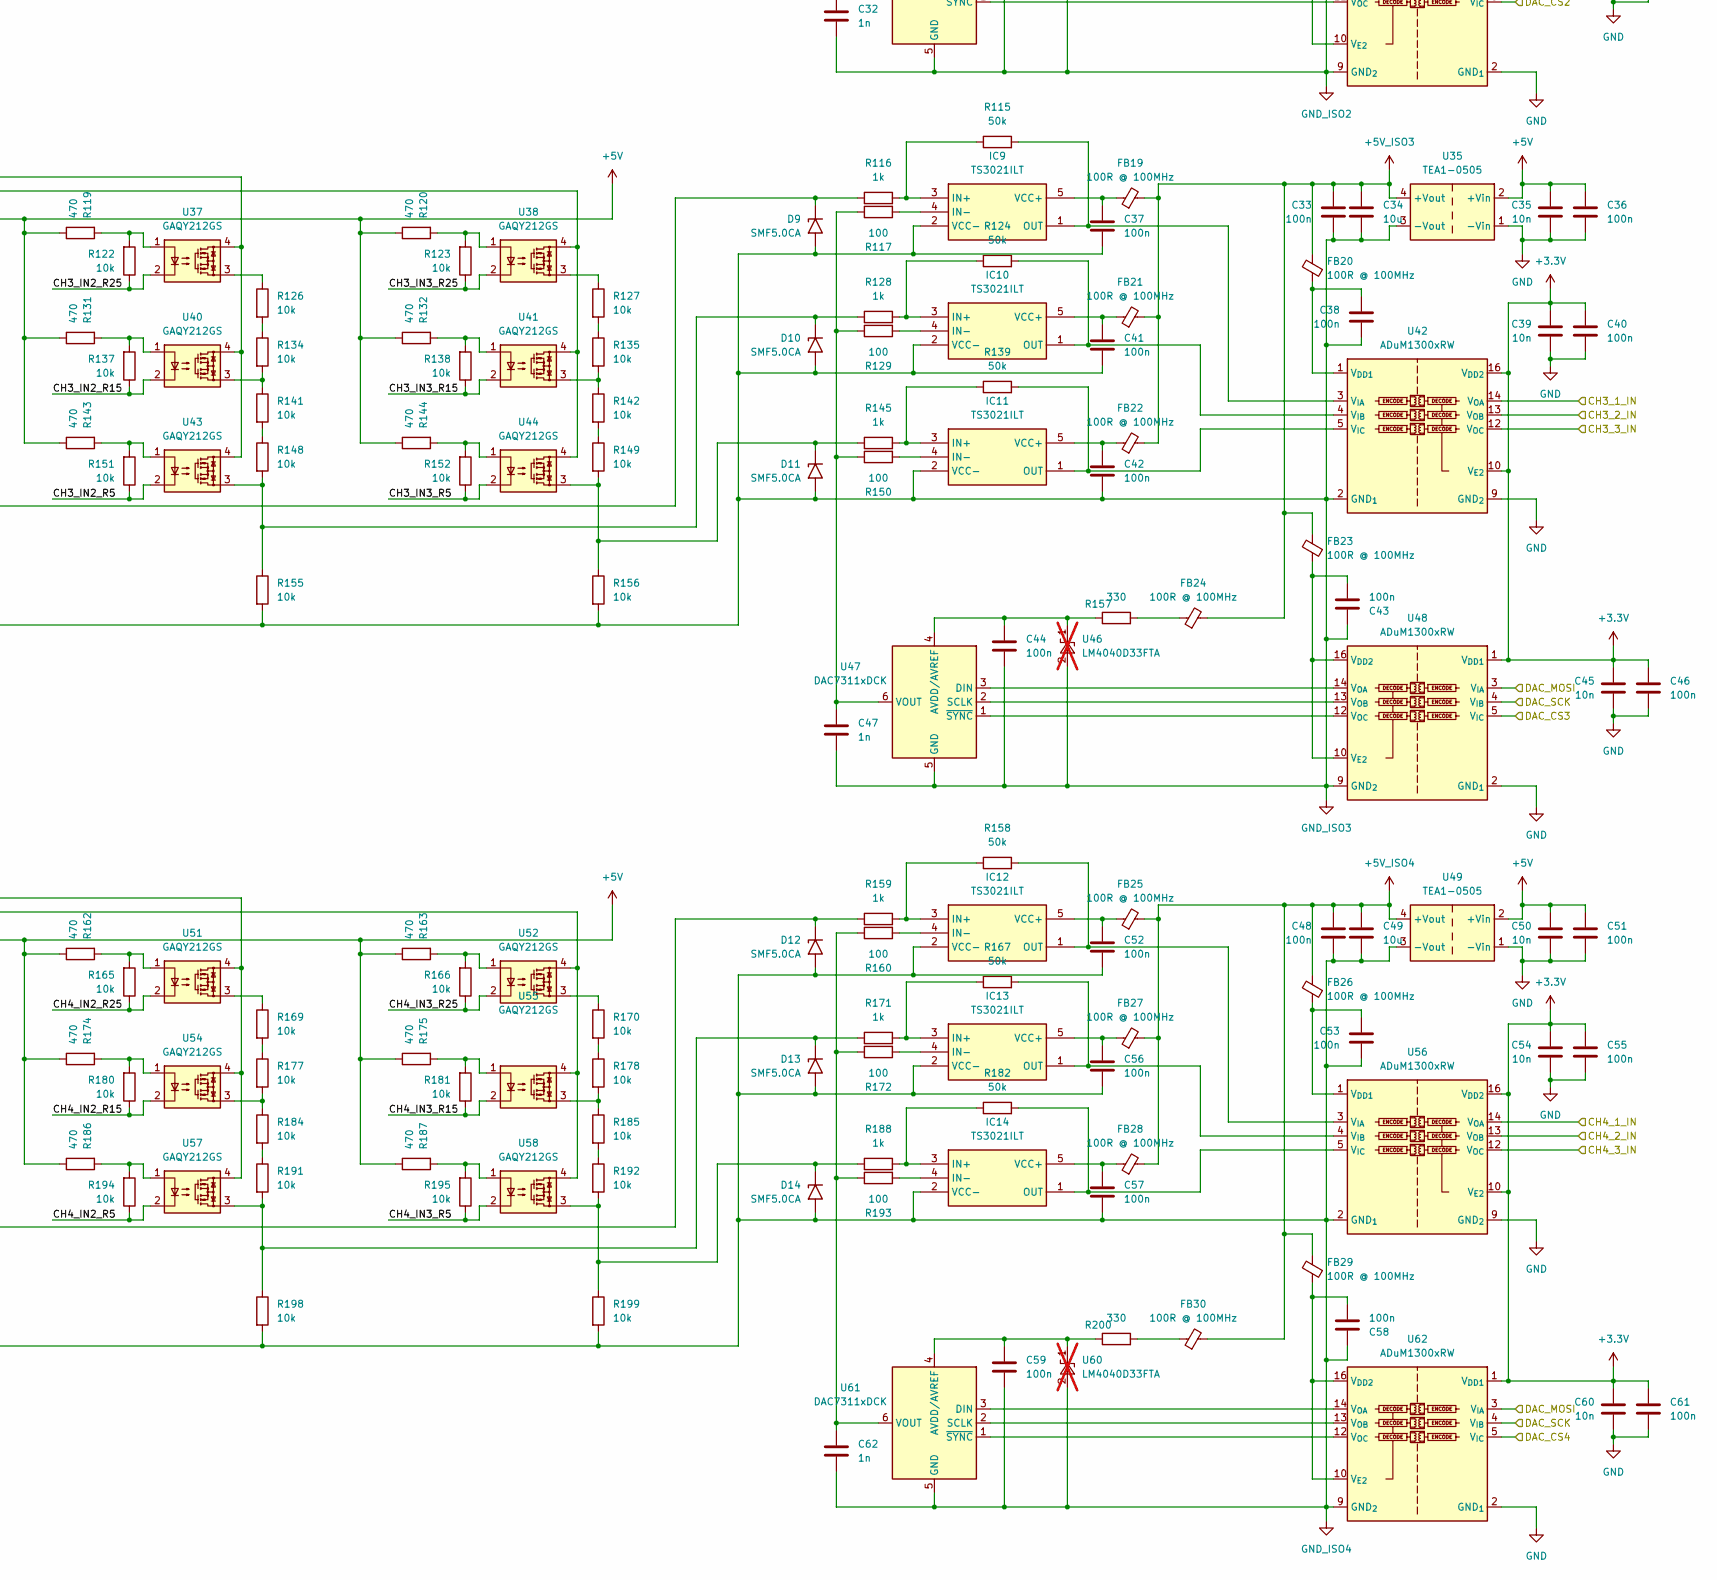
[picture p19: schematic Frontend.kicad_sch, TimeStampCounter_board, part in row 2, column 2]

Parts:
C1, C4, C5, C6, C8, C9, C10, C11, C12, C13, C15, C17, C20, C21, C22, C24, C25, C26, C27, C28, C29, C31, C33, C36, C37, C38, C40, C41, C42, C43, C44, C46, C48, C51, C52, C53, C55, C56, C57, C58, C59, C61, C64, C65, C66, C67, C68, C69, C70, C71: 100n; C_0603_1608Metric; Manufacturer_Part_Number GRM188R71H104KA93D
C2, C18, C34, C49: 10u; C_1206_3216Metric; Manufacturer_Part_Number CL31B106KBHNNNE
C3, C7, C14, C19, C23, C30, C35, C39, C45, C50, C54, C60: 10n; C_0603_1608Metric; Manufacturer_Part_Number GRM1885C1H103JA01J
C16, C32, C47, C62: 1n; C_0603_1608Metric; Manufacturer_Part_Number VJ0603A102JXACW1BC
D1, D2, D3, D4, D5, D6, D7, D8, D9, D10, D11, D12, D13, D14: SMF5.0CA; D_SMF; Manufacturer_Part_Number SMF5.0CA
D15, D16, D17, D18: D; D_SOD-323F; Manufacturer_Part_Number 1N4148
FB5, FB6, FB7, FB8, FB9, FB10, FB11, FB12, FB13, FB14, FB15, FB16, FB17, FB18, FB19, FB20, FB21, FB22, FB23, FB24, FB25, FB26, FB27, FB28, FB29, FB30: 100R @ 100MHz; L_0603_1608Metric; Manufacturer_Part_Number WLBD1608HCU101TL
IC1, IC2, IC3, IC4, IC5, IC6, IC7, IC8, IC9, IC10, IC11, IC12, IC13, IC14: TS3021ILT; SOT95P280X145-5N; Manufacturer_Part_Number TS3021ILT
IC15, IC16, IC17, IC18: NCP51460SN33T1G; SOT-23; Manufacturer_Part_Number NCP51460SN33T1G
J1, J2: Conn_01x05_Socket; PhoenixContact_MC_1,5_5-G-3.5_1x05_P3.50mm_Horizontal
J3, J4: Conn_01x04_Socket; PhoenixContact_MC_1,5_4-G-3.5_1x04_P3.50mm_Horizontal
R1, R12, R31, R50, R58, R69, R88, R107, R115, R124, R139, R158, R167, R182: 50k; R_0603_1608Metric
R2, R17, R39, R51, R59, R74, R96, R108, R116, R128, R145, R159, R171, R188: 1k; R_0603_1608Metric; Manufacturer_Part_Number ERA3AEB2212V
R3, R18, R45, R52, R60, R75, R102, R109, R117, R129, R150, R160, R172, R193: 100; R_0603_1608Metric
R4, R5, R6, R7, R19, R20, R21, R22, R36, R37, R38, R40, R61, R62, R63, R64, R76, R77, R78, R79, R93, R94, R95, R97, R118, R119, R120, R130, R131, R132, R143, R144, R146, R161, R162, R163, R173, R174, R175, R186, R187, R189: 470; R_0603_1608Metric
R8, R9, R10, R11, R13, R14, R15, R16, R23, R24, R25, R26, R27, R28, R29, R30, R32, R33, R34, R35, R41, R42, R43, R44, R46, R47, R48, R49, R53, R54, R55, R56, R65, R66, R67, R68, R70, R71, R72, R73, R80, R81, R82, R83, R84, R85, R86, R87, R89, R90, R91, R92, R98, R99, R100, R101, R103, R104, R105, R106, R110, R111, R112, R113, R121, R122, R123, R125, R126, R127, R133, R134, R135, R136, R137, R138, R140, R141, R142, R147, R148, R149, R151, R152, R153, R154, R155, R156, R164, R165, R166, R168, R169, R170, R176, R177, R178, R179, R180, R181, R183, R184, R185, R190, R191, R192, R194, R195, R196, R197, R198, R199, R201, R202, R203, R204: 10k; R_0603_1608Metric; Manufacturer_Part_Number CRCW060310K0FKTABC
R57, R114, R157, R200: 330; R_0603_1608Metric; Manufacturer_Part_Number 0603SAF3300T5E
TP3, TP4, TP7, TP10, TP11, TP12, TP13, TP14, TP15, TP16, TP17, TP18: TestPoint; TestPoint_Pad_D1.0mm
U1, U18, U35, U49: TEA1-0505; Converter_DCDC_TRACO_TEA1-xxxx_THT; Manufacturer_Part_Number TEA1-0505
U2, U3, U4, U5, U6, U7, U8, U9, U11, U12, U13, U14, U19, U20, U21, U22, U23, U24, U25, U26, U28, U29, U30, U31, U36, U37, U38, U39, U40, U41, U43, U44, U45, U50, U51, U52, U53, U54, U55, U57, U58, U59: GAQY212GS; SOP-4_3.8x4.1mm_P2.54mm; Manufacturer_Part_Number GAQY212GS
U10, U27: ADuM1400xRW; SOIC-16W_7.5x10.3mm_P1.27mm; Manufacturer_Part_Number ADuM1400BRW
U15, U32, U46, U60: LM4040D33FTA; SOT-23; Manufacturer_Part_Number LM4040D33FTA; not fitted
U16, U33, U47, U61: DAC7311xDCK; SOT-363_SC-70-6; Manufacturer_Part_Number DAC7311IDCK
U17, U34, U42, U48, U56, U62: ADuM1300xRW; SOIC-16W_7.5x10.3mm_P1.27mm; Manufacturer_Part_Number ADuM1300BRW
U64, U65, U66, U67: STM32C011F4Px; TSSOP-20_4.4x6.5mm_P0.65mm; Manufacturer_Part_Number STM32C011F4P6

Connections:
+3.3V: C7.2, C8.1, C14.2, C15.1, C23.2, C24.1, C30.2, C31.1, C39.2, C40.1, C45.2, C46.1, C54.2, C55.1, C60.2, C61.1, U10.10 (VE2), U10.16 (VDD2), U17.1 (V_{DD1}), U27.10 (VE2), U27.16 (VDD2), U34.1 (V_{DD1}), U42.10 (V_{E2}), U42.16 (V_{DD2}), U48.1 (V_{DD1}), U56.10 (V_{E2}), U56.16 (V_{DD2}), U62.1 (V_{DD1}); also elsewhere on the board
+5V: C3.2, C4.1, C19.2, C20.1, C35.2, C36.1, C50.2, C51.1, C65.1, C67.1, C69.1, C71.1, IC15.1 (VIN), IC16.1 (VIN), IC17.1 (VIN), IC18.1 (VIN), R4.1, R5.1, R6.1, R7.1, R19.1, R20.1, R21.1, R22.1, R36.1, R37.1, R38.1, R40.1, R61.1, R62.1, R63.1, R64.1, R76.1, R77.1, R78.1, R79.1, R93.1, R94.1, R95.1, R97.1, R118.1, R119.1, R120.1, R130.1, R131.1, R132.1, R143.1, R144.1, R146.1, R161.1, R162.1, R163.1, R173.1, R174.1, R175.1, R186.1, R187.1, R189.1, U1.2 (+Vin), U18.2 (+Vin), U35.2 (+Vin), U49.2 (+Vin); also elsewhere on the board
+5V_ISO1: C1.2, C2.1, FB5.2, FB6.2, FB7.2, FB8.2, FB9.2, FB10.2, FB11.2, U1.4 (+Vout)
+5V_ISO2: C17.2, C18.1, FB12.2, FB13.2, FB14.2, FB15.2, FB16.2, FB17.2, FB18.2, U18.4 (+Vout)
+5V_ISO3: C33.2, C34.1, FB19.2, FB20.2, FB21.2, FB22.2, FB23.2, FB24.2, U35.4 (+Vout)
+5V_ISO4: C48.2, C49.1, FB25.2, FB26.2, FB27.2, FB28.2, FB29.2, FB30.2, U49.4 (+Vout)
/Conn/DAC_CS1: U17.5 (V_{IC}); also elsewhere on the board
/Conn/DAC_CS2: U34.5 (V_{IC}); also elsewhere on the board
/Conn/DAC_CS3: U48.5 (V_{IC}); also elsewhere on the board
/Conn/DAC_CS4: U62.5 (V_{IC}); also elsewhere on the board
/Conn/DAC_MOSI: U17.3 (V_{IA}), U34.3 (V_{IA}), U48.3 (V_{IA}), U62.3 (V_{IA}); also elsewhere on the board
/Conn/DAC_SCK: U17.4 (V_{IB}), U34.4 (V_{IB}), U48.4 (V_{IB}), U62.4 (V_{IB}); also elsewhere on the board
/Conn/LPTIM1_IN1: U42.14 (V_{OA}); also elsewhere on the board
/Conn/LPTIM3_IN1: U42.13 (V_{OB}); also elsewhere on the board
/Conn/LPTIM4_IN1: U42.12 (V_{OC}); also elsewhere on the board
/Conn/TIM1_ETR: U56.14 (V_{OA}); also elsewhere on the board
/Conn/TIM2_CH1: U27.14 (VOA); also elsewhere on the board
/Conn/TIM2_CH2: U27.13 (VOB); also elsewhere on the board
/Conn/TIM2_CH3: U27.12 (VOC); also elsewhere on the board
/Conn/TIM2_CH4: U27.11 (VOD); also elsewhere on the board
/Conn/TIM3_ETR: U56.13 (V_{OB}); also elsewhere on the board
/Conn/TIM4_ETR: U56.12 (V_{OC}); also elsewhere on the board
/Conn/TIM5_CH1: U10.14 (VOA); also elsewhere on the board
/Conn/TIM5_CH2: U10.13 (VOB); also elsewhere on the board
/Conn/TIM5_CH3: U10.12 (VOC); also elsewhere on the board
/Conn/TIM5_CH4: U10.11 (VOD); also elsewhere on the board
/Conn/UART_RX: U64.1 (USART1_RX), U65.1 (USART1_RX), U66.1 (USART1_RX), U67.1 (USART1_RX); also elsewhere on the board
/Conn/UART_TX: D15.2 (A), D16.2 (A), D17.2 (A), D18.2 (A); also elsewhere on the board
/Frontend/CH1_IN1_R5: R49.1, U14.2, U64.7 (PA0)
/Frontend/CH1_IN1_R15: R27.1, U6.2, U64.8 (PA1)
/Frontend/CH1_IN1_R25: R8.1, U2.2, U64.9 (PA2)
/Frontend/CH1_IN2_R5: R46.1, U11.2, U64.10 (PA3)
/Frontend/CH1_IN2_R15: R28.1, U7.2, U64.11 (PA4)
/Frontend/CH1_IN2_R25: R9.1, U3.2, U64.12 (PA5)
/Frontend/CH1_IN3_R5: R47.1, U12.2, U64.13 (PA6)
/Frontend/CH1_IN3_R15: R29.1, U8.2, U64.14 (PA7)
/Frontend/CH1_IN3_R25: R10.1, U4.2, U64.15 (PA8)
/Frontend/CH1_IN4_R5: R48.1, U13.2, U64.16 (PA9/PA11)
/Frontend/CH1_IN4_R15: R30.1, U9.2, U64.17 (PA10/PA12)
/Frontend/CH1_IN4_R25: R11.1, U5.2, U64.20 (PB6)
/Frontend/CH2_IN1_R5: R106.1, U31.2, U65.7 (PA0)
/Frontend/CH2_IN1_R15: R84.1, U23.2, U65.8 (PA1)
/Frontend/CH2_IN1_R25: R65.1, U19.2, U65.9 (PA2)
/Frontend/CH2_IN2_R5: R103.1, U28.2, U65.10 (PA3)
/Frontend/CH2_IN2_R15: R85.1, U24.2, U65.11 (PA4)
/Frontend/CH2_IN2_R25: R66.1, U20.2, U65.12 (PA5)
/Frontend/CH2_IN3_R5: R104.1, U29.2, U65.13 (PA6)
/Frontend/CH2_IN3_R15: R86.1, U25.2, U65.14 (PA7)
/Frontend/CH2_IN3_R25: R67.1, U21.2, U65.15 (PA8)
/Frontend/CH2_IN4_R5: R105.1, U30.2, U65.16 (PA9/PA11)
/Frontend/CH2_IN4_R15: R87.1, U26.2, U65.17 (PA10/PA12)
/Frontend/CH2_IN4_R25: R68.1, U22.2, U65.20 (PB6)
/Frontend/CH3_IN1_R5: R153.1, U45.2, U66.7 (PA0)
/Frontend/CH3_IN1_R15: R136.1, U39.2, U66.8 (PA1)
/Frontend/CH3_IN1_R25: R121.1, U36.2, U66.9 (PA2)
/Frontend/CH3_IN2_R5: R151.1, U43.2, U66.10 (PA3)
/Frontend/CH3_IN2_R15: R137.1, U40.2, U66.11 (PA4)
/Frontend/CH3_IN2_R25: R122.1, U37.2, U66.12 (PA5)
/Frontend/CH3_IN3_R5: R152.1, U44.2, U66.13 (PA6)
/Frontend/CH3_IN3_R15: R138.1, U41.2, U66.14 (PA7)
/Frontend/CH3_IN3_R25: R123.1, U38.2, U66.15 (PA8)
/Frontend/CH4_IN1_R5: R196.1, U59.2, U67.7 (PA0)
/Frontend/CH4_IN1_R15: R179.1, U53.2, U67.8 (PA1)
/Frontend/CH4_IN1_R25: R164.1, U50.2, U67.9 (PA2)
/Frontend/CH4_IN2_R5: R194.1, U57.2, U67.10 (PA3)
/Frontend/CH4_IN2_R15: R180.1, U54.2, U67.11 (PA4)
/Frontend/CH4_IN2_R25: R165.1, U51.2, U67.12 (PA5)
/Frontend/CH4_IN3_R5: R195.1, U58.2, U67.13 (PA6)
/Frontend/CH4_IN3_R15: R181.1, U55.2, U67.14 (PA7)
/Frontend/CH4_IN3_R25: R166.1, U52.2, U67.15 (PA8)
GND: C3.1, C4.2, C7.1, C8.2, C14.1, C15.2, C19.1, C20.2, C23.1, C24.2, C30.1, C31.2, C35.1, C36.2, C39.1, C40.2, C45.1, C46.2, C50.1, C51.2, C54.1, C55.2, C60.1, C61.2, C64.2, C65.2, C66.2, C67.2, C68.2, C69.2, C70.2, C71.2, IC15.3 (GND), IC16.3 (GND), IC17.3 (GND), IC18.3 (GND), R201.2, R202.2, U1.1 (-Vin), U10.9 (GND2), U10.15 (GND2), U17.2 (GND_{1}), U17.8 (GND_{1}), U18.1 (-Vin), U27.9 (GND2), U27.15 (GND2), U34.2 (GND_{1}), U34.8 (GND_{1}), U35.1 (-Vin), U42.9 (GND_{2}), U42.15 (GND_{2}), U48.2 (GND_{1}), U48.8 (GND_{1}), U49.1 (-Vin), U56.9 (GND_{2}), U56.15 (GND_{2}), U62.2 (GND_{1}), U62.8 (GND_{1}), U64.5 (VSS), U65.5 (VSS), U66.5 (VSS), U67.5 (VSS); also elsewhere on the board
GND_ISO1: C1.1, C2.2, C5.2, C6.1, C9.2, C10.2, C11.2, C12.2, C13.2, C16.2, D1.2 (A2), D2.2 (A2), D3.2 (A2), D4.2 (A2), IC1.2 (VCC-), IC2.2 (VCC-), IC3.2 (VCC-), IC4.2 (VCC-), J1.5, R53.2, R54.2, R55.2, R56.2, U1.3 (-Vout), U10.2 (GND1), U10.8 (GND1), U15.2 (A), U16.5 (GND), U17.9 (GND_{2}), U17.15 (GND_{2})
GND_ISO2: C17.1, C18.2, C21.2, C22.1, C25.2, C26.2, C27.2, C28.2, C29.2, C32.2, D5.2 (A2), D6.2 (A2), D7.2 (A2), D8.2 (A2), IC5.2 (VCC-), IC6.2 (VCC-), IC7.2 (VCC-), IC8.2 (VCC-), J2.5, R110.2, R111.2, R112.2, R113.2, U18.3 (-Vout), U27.2 (GND1), U27.8 (GND1), U32.2 (A), U33.5 (GND), U34.9 (GND_{2}), U34.15 (GND_{2})
GND_ISO3: C33.1, C34.2, C37.2, C38.1, C41.2, C42.2, C43.2, C44.2, C47.2, D9.2 (A2), D10.2 (A2), D11.2 (A2), IC9.2 (VCC-), IC10.2 (VCC-), IC11.2 (VCC-), J3.4, R154.2, R155.2, R156.2, U35.3 (-Vout), U42.2 (GND_{1}), U42.8 (GND_{1}), U46.2 (A), U47.5 (GND), U48.9 (GND_{2}), U48.15 (GND_{2})
GND_ISO4: C48.1, C49.2, C52.2, C53.1, C56.2, C57.2, C58.2, C59.2, C62.2, D12.2 (A2), D13.2 (A2), D14.2 (A2), IC12.2 (VCC-), IC13.2 (VCC-), IC14.2 (VCC-), J4.4, R197.2, R198.2, R199.2, U49.3 (-Vout), U56.2 (GND_{1}), U56.8 (GND_{1}), U60.2 (A), U61.5 (GND), U62.9 (GND_{2}), U62.15 (GND_{2})
unnamed: D1.1 (A1), R2.1, R41.2, R53.1, U14.3
unnamed: D2.1 (A1), R17.1, R42.2, R54.1, U11.3
unnamed: D3.1 (A1), R39.1, R43.2, R55.1, U12.3
unnamed: D4.1 (A1), R44.2, R51.1, R56.1, U13.3
unnamed: D5.1 (A1), R59.1, R98.2, R110.1, U31.3
unnamed: D6.1 (A1), R74.1, R99.2, R111.1, U28.3
unnamed: D7.1 (A1), R96.1, R100.2, R112.1, U29.3
unnamed: D8.1 (A1), R101.2, R108.1, R113.1, U30.3
unnamed: D9.1 (A1), R116.1, R147.2, R154.1, U45.3
unnamed: D10.1 (A1), R128.1, R148.2, R155.1, U43.3
unnamed: D11.1 (A1), R145.1, R149.2, R156.1, U44.3
unnamed: D12.1 (A1), R159.1, R190.2, R197.1, U59.3
unnamed: D13.1 (A1), R171.1, R191.2, R198.1, U57.3
unnamed: D14.1 (A1), R188.1, R192.2, R199.1, U58.3
unnamed: D15.1 (K), U65.2 (USART1_TX)
unnamed: D16.1 (K), U64.2 (USART1_TX)
unnamed: D17.1 (K), U66.2 (USART1_TX)
unnamed: D18.1 (K), U67.2 (USART1_TX)
unnamed: FB11.1, R57.2
unnamed: FB18.1, R114.2
unnamed: FB24.1, R157.2
unnamed: FB30.1, R200.2
unnamed: IC1.3 (IN+), R1.1, R2.2
unnamed: IC1.4 (IN-), R3.2
unnamed: IC1.1 (OUT), R1.2, U10.3 (VIA)
unnamed: C5.1, FB5.1, IC1.5 (VCC+)
unnamed: IC2.3 (IN+), R12.1, R17.2
unnamed: IC2.4 (IN-), R18.2
unnamed: IC2.1 (OUT), R12.2, U10.4 (VIB)
unnamed: C9.1, FB7.1, IC2.5 (VCC+)
unnamed: IC3.3 (IN+), R31.1, R39.2
unnamed: IC3.4 (IN-), R45.2
unnamed: IC3.1 (OUT), R31.2, U10.5 (VIC)
unnamed: C10.1, FB8.1, IC3.5 (VCC+)
unnamed: IC4.3 (IN+), R50.1, R51.2
unnamed: IC4.4 (IN-), R52.2
unnamed: IC4.1 (OUT), R50.2, U10.6 (VID)
unnamed: C11.1, FB9.1, IC4.5 (VCC+)
unnamed: IC5.3 (IN+), R58.1, R59.2
unnamed: IC5.4 (IN-), R60.2
unnamed: IC5.1 (OUT), R58.2, U27.3 (VIA)
unnamed: C21.1, FB12.1, IC5.5 (VCC+)
unnamed: IC6.3 (IN+), R69.1, R74.2
unnamed: IC6.4 (IN-), R75.2
unnamed: IC6.1 (OUT), R69.2, U27.4 (VIB)
unnamed: C25.1, FB14.1, IC6.5 (VCC+)
unnamed: IC7.3 (IN+), R88.1, R96.2
unnamed: IC7.4 (IN-), R102.2
unnamed: IC7.1 (OUT), R88.2, U27.5 (VIC)
unnamed: C26.1, FB15.1, IC7.5 (VCC+)
unnamed: IC8.3 (IN+), R107.1, R108.2
unnamed: IC8.4 (IN-), R109.2
unnamed: IC8.1 (OUT), R107.2, U27.6 (VID)
unnamed: C27.1, FB16.1, IC8.5 (VCC+)
unnamed: IC9.3 (IN+), R115.1, R116.2
unnamed: IC9.4 (IN-), R117.2
unnamed: IC9.1 (OUT), R115.2, U42.3 (V_{IA})
unnamed: C37.1, FB19.1, IC9.5 (VCC+)
unnamed: IC10.3 (IN+), R124.1, R128.2
unnamed: IC10.4 (IN-), R129.2
unnamed: IC10.1 (OUT), R124.2, U42.4 (V_{IB})
unnamed: C41.1, FB21.1, IC10.5 (VCC+)
unnamed: IC11.3 (IN+), R139.1, R145.2
unnamed: IC11.4 (IN-), R150.2
unnamed: IC11.1 (OUT), R139.2, U42.5 (V_{IC})
unnamed: C42.1, FB22.1, IC11.5 (VCC+)
unnamed: IC12.3 (IN+), R158.1, R159.2
unnamed: IC12.4 (IN-), R160.2
unnamed: IC12.1 (OUT), R158.2, U56.3 (V_{IA})
unnamed: C52.1, FB25.1, IC12.5 (VCC+)
unnamed: IC13.3 (IN+), R167.1, R171.2
unnamed: IC13.4 (IN-), R172.2
unnamed: IC13.1 (OUT), R167.2, U56.4 (V_{IB})
unnamed: C56.1, FB27.1, IC13.5 (VCC+)
unnamed: IC14.3 (IN+), R182.1, R188.2
unnamed: IC14.4 (IN-), R193.2
unnamed: IC14.1 (OUT), R182.2, U56.5 (V_{IC})
unnamed: C57.1, FB28.1, IC14.5 (VCC+)
unnamed: C64.1, IC15.2 (VOUT), U64.4 (VDD)
unnamed: C66.1, IC16.2 (VOUT), U65.4 (VDD)
unnamed: C68.1, IC17.2 (VOUT), R203.1, U66.4 (VDD)
unnamed: C70.1, IC18.2 (VOUT), R204.1, U67.4 (VDD)
unnamed: J1.1, U2.4, U6.4, U14.4
unnamed: J1.2, U3.4, U7.4, U11.4
unnamed: J1.3, U4.4, U8.4, U12.4
unnamed: J1.4, U5.4, U9.4, U13.4
unnamed: J2.1, U19.4, U23.4, U31.4
unnamed: J2.2, U20.4, U24.4, U28.4
unnamed: J2.3, U21.4, U25.4, U29.4
unnamed: J2.4, U22.4, U26.4, U30.4
unnamed: J3.1, U36.4, U39.4, U45.4
unnamed: J3.2, U37.4, U40.4, U43.4
unnamed: J3.3, U38.4, U41.4, U44.4
unnamed: J4.1, U50.4, U53.4, U59.4
unnamed: J4.2, U51.4, U54.4, U57.4
unnamed: J4.3, U52.4, U55.4, U58.4
unnamed: R4.2, R8.2, U2.1
unnamed: R5.2, R9.2, U3.1
unnamed: R6.2, R10.2, U4.1
unnamed: R7.2, R11.2, U5.1
unnamed: R13.1, U2.3
unnamed: R13.2, R23.1
unnamed: R14.1, U3.3
unnamed: R14.2, R24.1
unnamed: R15.1, U4.3
unnamed: R15.2, R25.1
unnamed: R16.1, U5.3
unnamed: R16.2, R26.1
unnamed: R19.2, R27.2, U6.1
unnamed: R20.2, R28.2, U7.1
unnamed: R21.2, R29.2, U8.1
unnamed: R22.2, R30.2, U9.1
unnamed: R23.2, R32.1, U6.3
unnamed: R24.2, R33.1, U7.3
unnamed: R25.2, R34.1, U8.3
unnamed: R26.2, R35.1, U9.3
unnamed: R32.2, R41.1
unnamed: R33.2, R42.1
unnamed: R34.2, R43.1
unnamed: R35.2, R44.1
unnamed: R36.2, R46.2, U11.1
unnamed: R37.2, R47.2, U12.1
unnamed: R38.2, R48.2, U13.1
unnamed: R40.2, R49.2, U14.1
unnamed: R61.2, R65.2, U19.1
unnamed: R62.2, R66.2, U20.1
unnamed: R63.2, R67.2, U21.1
unnamed: R64.2, R68.2, U22.1
unnamed: R70.1, U19.3
unnamed: R70.2, R80.1
unnamed: R71.1, U20.3
unnamed: R71.2, R81.1
unnamed: R72.1, U21.3
unnamed: R72.2, R82.1
unnamed: R73.1, U22.3
unnamed: R73.2, R83.1
unnamed: R76.2, R84.2, U23.1
unnamed: R77.2, R85.2, U24.1
unnamed: R78.2, R86.2, U25.1
unnamed: R79.2, R87.2, U26.1
unnamed: R80.2, R89.1, U23.3
unnamed: R81.2, R90.1, U24.3
unnamed: R82.2, R91.1, U25.3
unnamed: R83.2, R92.1, U26.3
unnamed: R89.2, R98.1
unnamed: R90.2, R99.1
unnamed: R91.2, R100.1
unnamed: R92.2, R101.1
unnamed: R93.2, R103.2, U28.1
unnamed: R94.2, R104.2, U29.1
unnamed: R95.2, R105.2, U30.1
unnamed: R97.2, R106.2, U31.1
unnamed: R118.2, R121.2, U36.1
unnamed: R119.2, R122.2, U37.1
unnamed: R120.2, R123.2, U38.1
unnamed: R125.1, U36.3
unnamed: R125.2, R133.1
unnamed: R126.1, U37.3
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

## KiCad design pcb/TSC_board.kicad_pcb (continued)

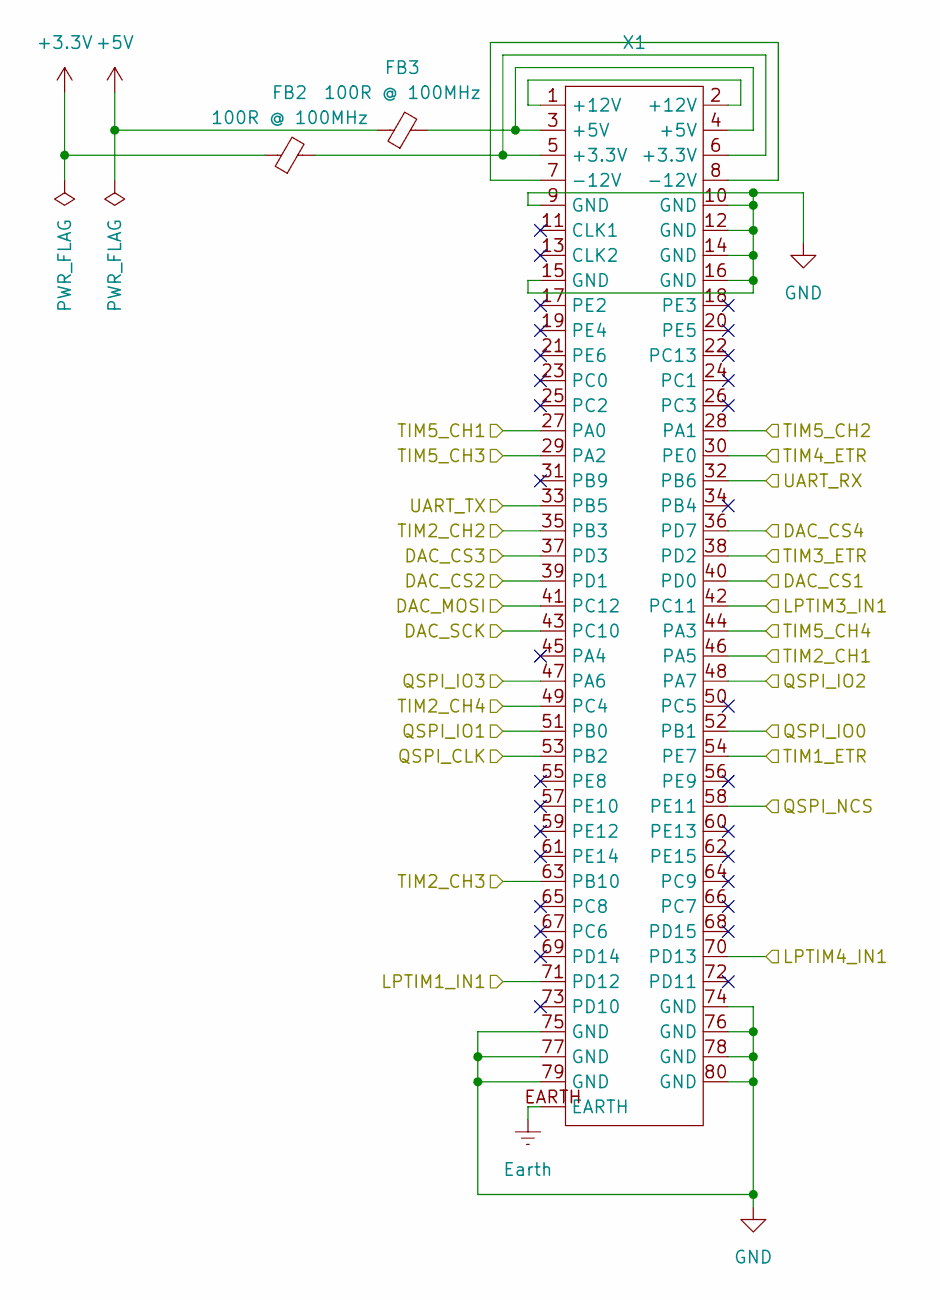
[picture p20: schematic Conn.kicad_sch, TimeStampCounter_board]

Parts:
FB2, FB3: 100R @ 100MHz; L_0603_1608Metric; Manufacturer_Part_Number WLBD1608HCU101TL
X1: UCB_conn

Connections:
+3.3V: FB2.1; also elsewhere on the board
+5V: FB3.1; also elsewhere on the board
/Conn/DAC_CS1: X1.40 (PD0); also elsewhere on the board
/Conn/DAC_CS2: X1.39 (PD1); also elsewhere on the board
/Conn/DAC_CS3: X1.37 (PD3); also elsewhere on the board
/Conn/DAC_CS4: X1.36 (PD7); also elsewhere on the board
/Conn/DAC_MOSI: X1.41 (PC12); also elsewhere on the board
/Conn/DAC_SCK: X1.43 (PC10); also elsewhere on the board
/Conn/LPTIM1_IN1: X1.71 (PD12); also elsewhere on the board
/Conn/LPTIM3_IN1: X1.42 (PC11); also elsewhere on the board
/Conn/LPTIM4_IN1: X1.70 (PD13); also elsewhere on the board
/Conn/QSPI_CLK: X1.53 (PB2); also elsewhere on the board
/Conn/QSPI_IO0: X1.52 (PB1); also elsewhere on the board
/Conn/QSPI_IO1: X1.51 (PB0); also elsewhere on the board
/Conn/QSPI_IO2: X1.48 (PA7); also elsewhere on the board
/Conn/QSPI_IO3: X1.47 (PA6); also elsewhere on the board
/Conn/QSPI_NCS: X1.58 (PE11); also elsewhere on the board
/Conn/TIM1_ETR: X1.54 (PE7); also elsewhere on the board
/Conn/TIM2_CH1: X1.46 (PA5); also elsewhere on the board
/Conn/TIM2_CH2: X1.35 (PB3); also elsewhere on the board
/Conn/TIM2_CH3: X1.63 (PB10); also elsewhere on the board
/Conn/TIM2_CH4: X1.49 (PC4); also elsewhere on the board
/Conn/TIM3_ETR: X1.38 (PD2); also elsewhere on the board
/Conn/TIM4_ETR: X1.30 (PE0); also elsewhere on the board
/Conn/TIM5_CH1: X1.27 (PA0); also elsewhere on the board
/Conn/TIM5_CH2: X1.28 (PA1); also elsewhere on the board
/Conn/TIM5_CH3: X1.29 (PA2); also elsewhere on the board
/Conn/TIM5_CH4: X1.44 (PA3); also elsewhere on the board
/Conn/UART_RX: X1.32 (PB6); also elsewhere on the board
/Conn/UART_TX: X1.33 (PB5); also elsewhere on the board
Earth: X1.EARTH
GND: X1.9 (GND), X1.10 (GND), X1.12 (GND), X1.14 (GND), X1.15 (GND), X1.16 (GND), X1.74 (GND), X1.75 (GND), X1.76 (GND), X1.77 (GND), X1.78 (GND), X1.79 (GND), X1.80 (GND); also elsewhere on the board
unnamed: FB2.2, X1.5 (+3.3V), X1.6 (+3.3V)
unnamed: FB3.2, X1.3 (+5V), X1.4 (+5V)
unnamed: X1.1 (+12V), X1.2 (+12V)
unnamed: X1.7 (-12V), X1.8 (-12V)

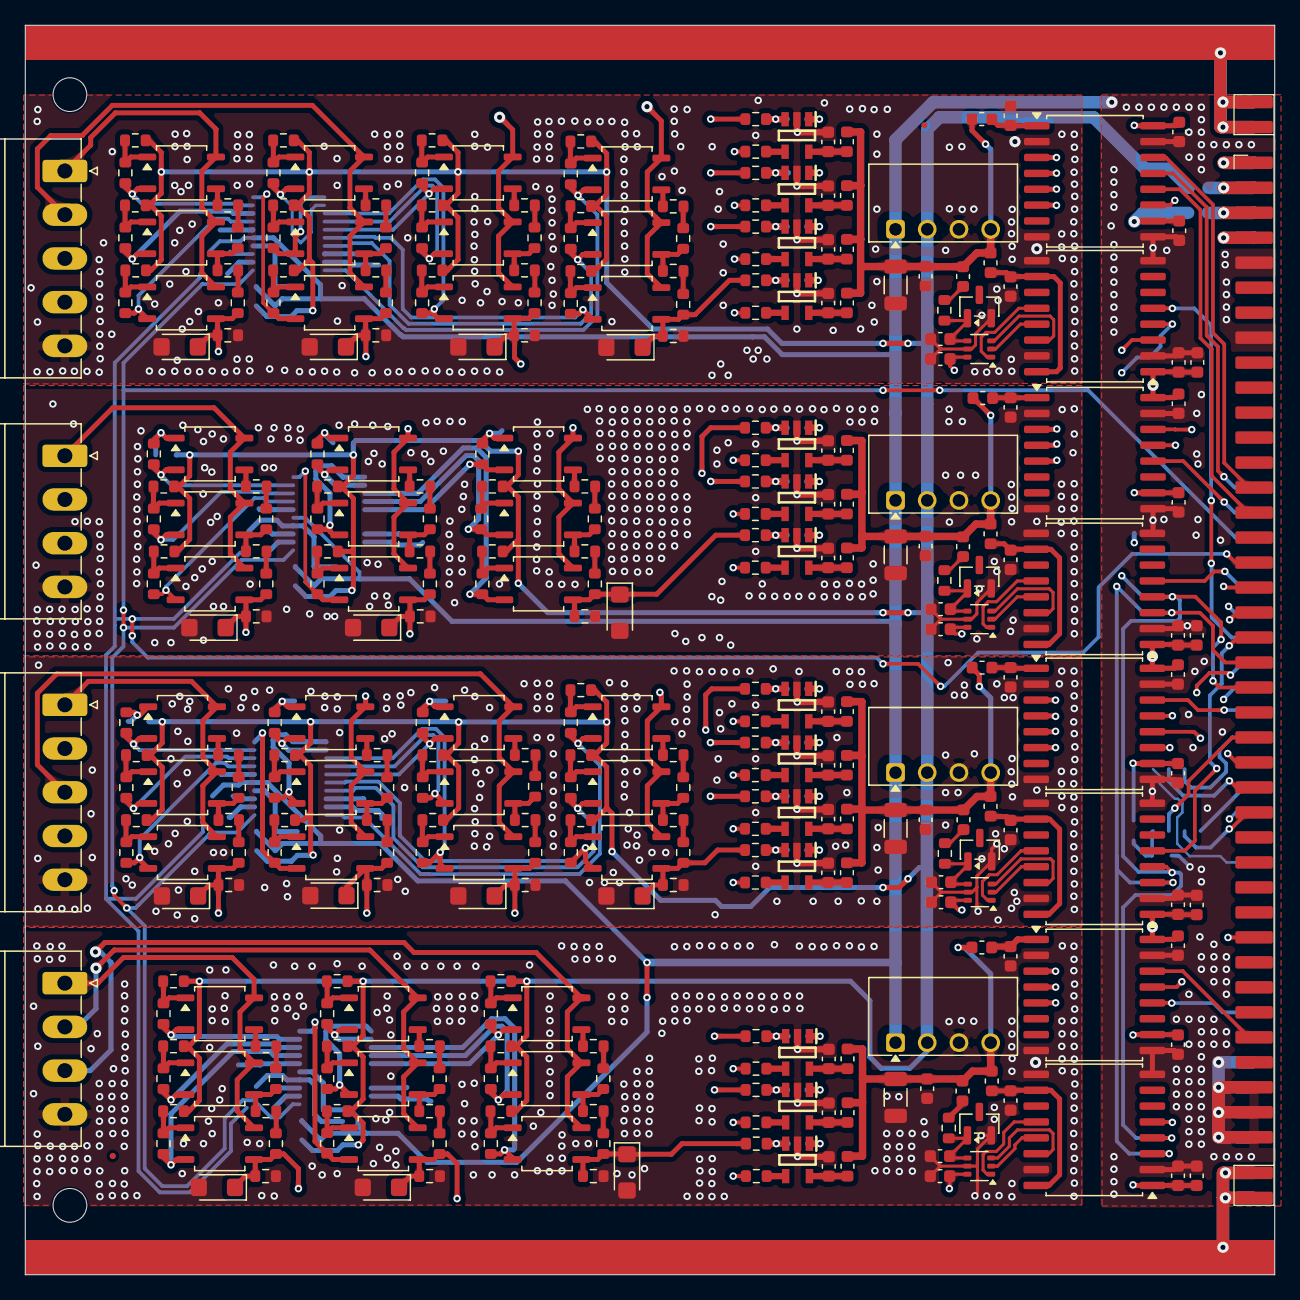
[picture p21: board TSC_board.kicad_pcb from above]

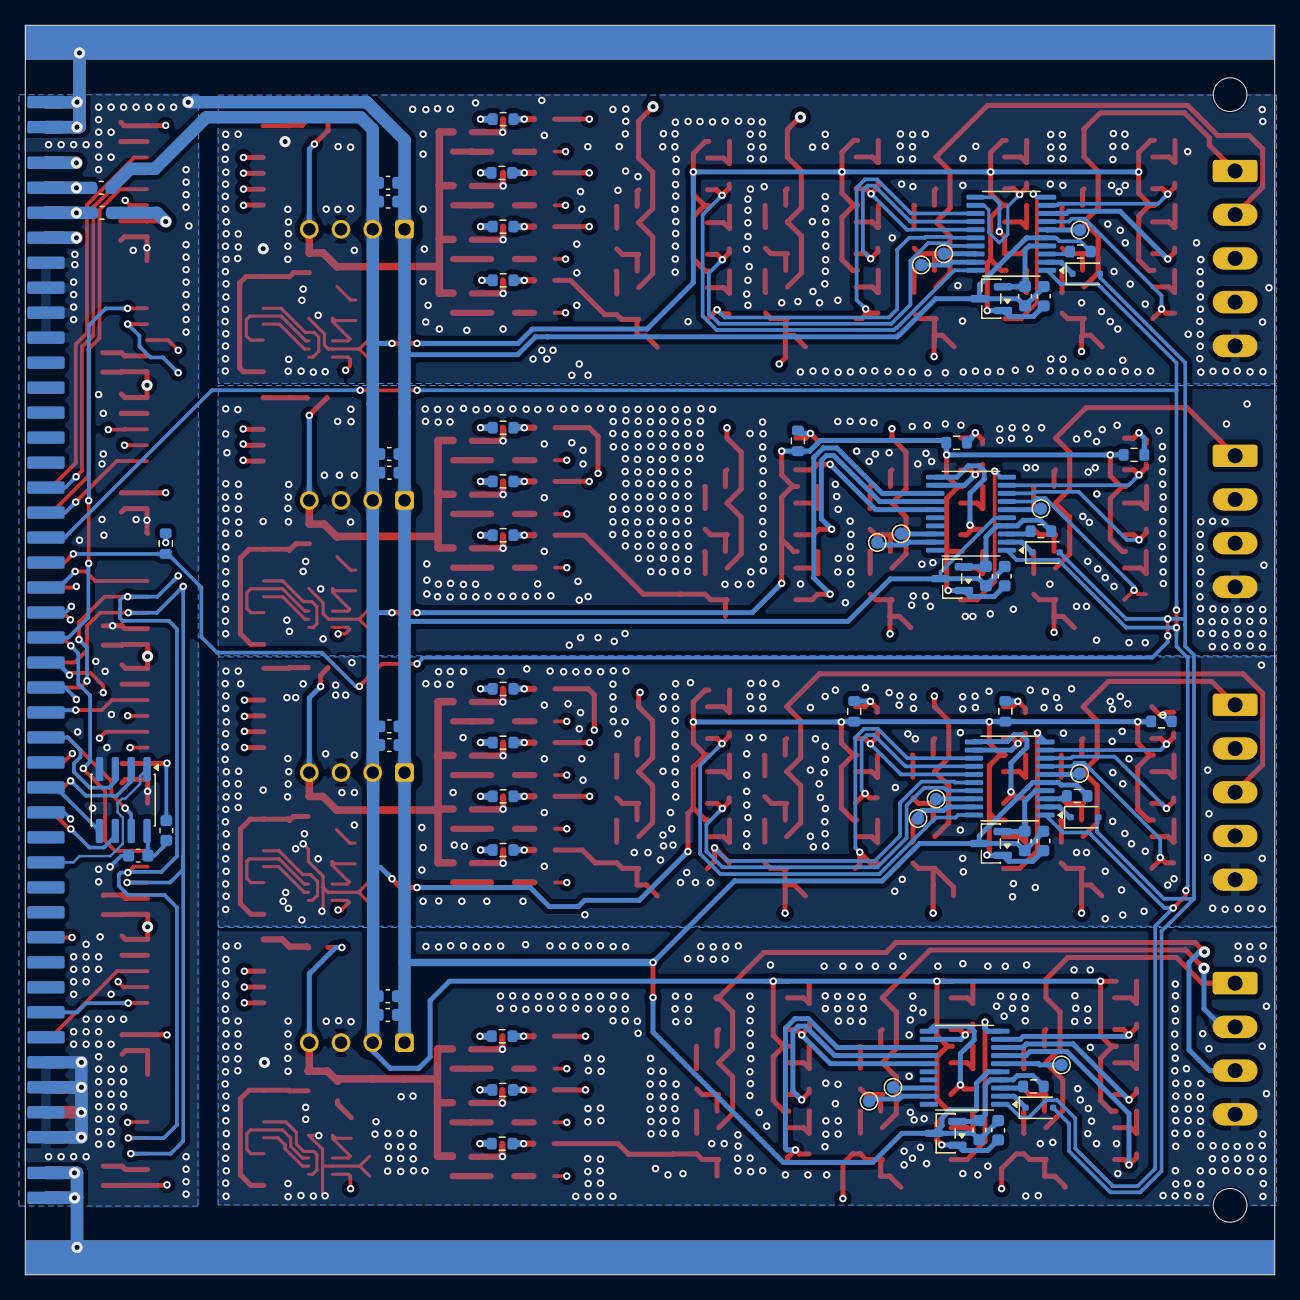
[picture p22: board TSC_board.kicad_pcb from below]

Board: 4 copper layers, 100.0 x 100.0 mm, 429 parts (70 on the bottom side), 324 nets.

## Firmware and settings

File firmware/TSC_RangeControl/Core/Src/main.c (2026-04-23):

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
/* Includes ------------------------------------------------------------------*/
#include "main.h"

/* USER CODE BEGIN Includes */
#include "gpio_ctrl.h"
#include "protocol.h"
/* USER CODE END Includes */


UART_HandleTypeDef huart1;

/* USER CODE BEGIN PV */
ChannelGPIO ch_map[4];

uint8_t rx_byte;
/* USER CODE END PV */

void SystemClock_Config(void);
static void MX_GPIO_Init(void);
static void MX_USART1_UART_Init(void);
/* USER CODE BEGIN PFP */
void HAL_UART_RxCpltCallback(UART_HandleTypeDef *huart)
{
    if (huart->Instance == USART1)
    {
        PROTOCOL_ProcessByte(rx_byte);
        HAL_UART_Receive_IT(&huart1, &rx_byte, 1);
    }
}
static uint8_t read_cfg_channels(void)
{
    // CFG = 0 -> 12 GPIO (4 kanały), CFG = 1 -> 9 GPIO (3 kanały)
    return (HAL_GPIO_ReadPin(CFG_GPIO_Port, CFG_Pin) == GPIO_PIN_SET) ? 3 : 4;
}
/* USER CODE END PFP */

/**
  * @brief  The application entry point.
  * @retval int
  */
int main(void)
{

  /* MCU Configuration--------------------------------------------------------*/

  /* Reset of all peripherals, Initializes the Flash interface and the Systick. */
  HAL_Init();

  /* Configure the system clock */
  SystemClock_Config();

  /* Initialize all configured peripherals */
  MX_GPIO_Init();
  MX_USART1_UART_Init();
  /* USER CODE BEGIN 2 */
	uint8_t channels = read_cfg_channels();

	GPIOCTRL_Init(channels);
	PROTOCOL_Init();

	// MAPA GPIO (przykład – CubeMX label INx_Ry)
	ch_map[0] = (ChannelGPIO ) { IN1_R1_GPIO_Port, IN1_R1_Pin,
			IN1_R2_GPIO_Port, IN1_R2_Pin,
			IN1_R3_GPIO_Port, IN1_R3_Pin };

	ch_map[1] = (ChannelGPIO ) { IN2_R1_GPIO_Port, IN2_R1_Pin,
			IN2_R2_GPIO_Port, IN2_R2_Pin,
			IN2_R3_GPIO_Port, IN2_R3_Pin };

	ch_map[2] = (ChannelGPIO ) { IN3_R1_GPIO_Port, IN3_R1_Pin,
			IN3_R2_GPIO_Port, IN3_R2_Pin,
			IN3_R3_GPIO_Port, IN3_R3_Pin };

	ch_map[3] = (ChannelGPIO ) { IN4_R1_GPIO_Port, IN4_R1_Pin,
			IN4_R2_GPIO_Port, IN4_R2_Pin,
			IN4_R3_GPIO_Port, IN4_R3_Pin };

	HAL_UART_Receive_IT(&huart1, &rx_byte, 1);

  /* USER CODE END 2 */

  /* Infinite loop */
  /* USER CODE BEGIN WHILE */
  while (1)
  {
	  __WFI(); // ultra low power
    /* USER CODE END WHILE */

    /* USER CODE BEGIN 3 */
  }
  /* USER CODE END 3 */
}

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


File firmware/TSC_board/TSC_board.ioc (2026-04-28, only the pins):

Mcu.UserName=STM32H563VITx
PA0.Signal=S_TIM5_CH1
PA1.Signal=S_TIM5_CH2
PA10.Signal=USART1_RX
PA11.Signal=USB_DM
PA12.Signal=USB_DP
PA13(JTMS/SWDIO).Signal=DEBUG_JTMS-SWDIO
PA14(JTCK/SWCLK).Signal=DEBUG_JTCK-SWCLK
PA15(JTDI).GPIO_Label=USB_DETECT
PA15(JTDI).Signal=GPIO_Input
PA2.Signal=S_TIM5_CH3
PA3.Signal=S_TIM5_CH4
PA5.Signal=S_TIM2_CH1
PA6.Signal=OCTOSPI1_IO3
PA7.Signal=OCTOSPI1_IO2
PA8.Signal=RCC_MCO_1
PA9.Signal=USART1_TX
PB0.Signal=OCTOSPI1_IO1
PB1.Signal=OCTOSPI1_IO0
PB10.Signal=S_TIM2_CH3
PB12.GPIO_Label=W5500_CS
PB12.Signal=GPIO_Output
PB13.GPIO_Label=W5500_SCK
PB13.Signal=SPI2_SCK
PB14.GPIO_Label=W5500_MISO
PB14.Signal=SPI2_MISO
PB15.GPIO_Label=W5500_MOSI
PB15.Signal=SPI2_MOSI
PB2.Signal=OCTOSPI1_CLK
PB3(JTDO/TRACESWO).Signal=S_TIM2_CH2
PB5.Signal=UART5_RX
PB6.Signal=UART5_TX
PB7.Signal=I2C1_SDA
PB8.Signal=I2C1_SCL
PC10.GPIO_Label=DAC_SCK
PC10.Signal=SPI3_SCK
PC11.Signal=LPTIM3_IN1
PC12.GPIO_Label=DAC_MOSI
PC12.Signal=SPI3_MOSI
PC14-OSC32_IN(OSC32_IN).Signal=GPIO_Output
PC15-OSC32_OUT(OSC32_OUT).Signal=GPIO_Output
PC4.Signal=S_TIM2_CH4
PD0.GPIO_Label=DAC_CS1
PD0.Signal=GPIO_Output
PD1.GPIO_Label=DAC_CS2
PD1.Signal=GPIO_Output
PD12.Signal=LPTIM1_IN1
PD13.Signal=LPTIM4_IN1
PD2.Signal=S_TIM3_ETR
PD3.GPIO_Label=DAC_CS3
PD3.Signal=GPIO_Output
PD4.Signal=USART2_DE
PD5.Signal=USART2_TX
PD6.Signal=USART2_RX
PD7.GPIO_Label=DAC_CS4
PD7.Signal=GPIO_Output
PD8.GPIO_Label=W5500_RST
PD8.Signal=GPIO_Output
PD9.GPIO_Label=W5500_INT
PD9.Signal=GPIO_Input
PE0.Signal=S_TIM4_ETR
PE11.Signal=OCTOSPI1_NCS
PE7.Signal=S_TIM1_ETR
PH0-OSC_IN(PH0).Signal=RCC_OSC_IN
PH1-OSC_OUT(PH1).Signal=RCC_OSC_OUT

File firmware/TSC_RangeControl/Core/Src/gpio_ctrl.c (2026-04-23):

/*
 * gpio_ctrl.c
 *
 *  Created on: 23 kwi 2026
 *      Author: bartkepl
 */


#include "gpio_ctrl.h"

static uint8_t g_channels = 0;

extern ChannelGPIO ch_map[4]; // zdefiniowane w main.c

void GPIOCTRL_Init(uint8_t channels)
{
    g_channels = channels;

    // wszystko OFF
    for (uint8_t i = 0; i < g_channels; i++) {
        GPIOCTRL_SetChannel(i, 0);
    }
}

static void set_off(ChannelGPIO *ch)
{
    HAL_GPIO_WritePin(ch->r1_port, ch->r1_pin, GPIO_PIN_SET);
    HAL_GPIO_WritePin(ch->r2_port, ch->r2_pin, GPIO_PIN_SET);
    HAL_GPIO_WritePin(ch->r3_port, ch->r3_pin, GPIO_PIN_SET);
}

void GPIOCTRL_SetChannel(uint8_t ch, uint8_t mode)
{
    if (ch >= g_channels) return;

    ChannelGPIO *c = &ch_map[ch];

    set_off(c);

    switch(mode)
    {
        case 1: HAL_GPIO_WritePin(c->r1_port, c->r1_pin, GPIO_PIN_RESET); break;
        case 2: HAL_GPIO_WritePin(c->r2_port, c->r2_pin, GPIO_PIN_RESET); break;
        case 3: HAL_GPIO_WritePin(c->r3_port, c->r3_pin, GPIO_PIN_RESET); break;
        default: break;
    }
}

void GPIOCTRL_Apply(uint8_t data4x2)
{
    for (uint8_t ch = 0; ch < g_channels; ch++)
    {
        uint8_t mode = (data4x2 >> (ch * 2)) & 0x03;
        GPIOCTRL_SetChannel(ch, mode);
    }
}

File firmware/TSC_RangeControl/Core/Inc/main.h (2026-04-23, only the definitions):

#define CFG_Pin GPIO_PIN_15
#define CFG_GPIO_Port GPIOC
#define IN1_R1_Pin GPIO_PIN_0
#define IN1_R1_GPIO_Port GPIOA
#define IN1_R2_Pin GPIO_PIN_1
#define IN1_R2_GPIO_Port GPIOA
#define IN1_R3_Pin GPIO_PIN_2
#define IN1_R3_GPIO_Port GPIOA
#define IN2_R1_Pin GPIO_PIN_3
#define IN2_R1_GPIO_Port GPIOA
#define IN2_R2_Pin GPIO_PIN_4
#define IN2_R2_GPIO_Port GPIOA
#define IN2_R3_Pin GPIO_PIN_5
#define IN2_R3_GPIO_Port GPIOA
#define IN3_R1_Pin GPIO_PIN_6
#define IN3_R1_GPIO_Port GPIOA
#define IN3_R2_Pin GPIO_PIN_7
#define IN3_R2_GPIO_Port GPIOA
#define IN3_R3_Pin GPIO_PIN_8
#define IN3_R3_GPIO_Port GPIOA
#define IN4_R1_Pin GPIO_PIN_11
#define IN4_R1_GPIO_Port GPIOA
#define IN4_R2_Pin GPIO_PIN_12
#define IN4_R2_GPIO_Port GPIOA
#define IN4_R3_Pin GPIO_PIN_6
#define IN4_R3_GPIO_Port GPIOB

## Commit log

2026-04-20 Change of concept, only frontend. To be connected with UCB_board
    [Frontend.kicad_sch, MCU.kicad_sch, TSC_board.kicad_pcb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]
2026-04-20 Add STM32 .ioc and adjust UCB connector footprint
    Add STM32CubeMX project file (firmware/TSC_board.ioc) for the STM32H563VITx MCU and update KiCad PCB/schematic files. Adjust UCB_conn footprint and apply corresponding changes to pcb TSC_board/Fronte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
    [Frontend.kicad_sch, MCU.kicad_sch, TSC_board.kicad_pcb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]
2026-04-21 More schematic
    [Frontend.kicad_sch, MCU.kicad_sch, TSC_board.kicad_pcb]
2026-04-21 Remove NL17SZ17 symbol; update schematic
    Delete the NL17SZ17DFT2G symbol from pcb/Frontend.kicad_sch and apply a bulk update to schematic. Many junction coordinates and UUIDs were regenerated/adjusted in Frontend.kicad_sch; related KiCad fi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
    [Frontend.kicad_sch, MCU.kicad_sch, TSC_board.kicad_pcb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]
2026-04-22 Update TSC_board schematic and layout
    [Conn.kicad_sch, Frontend.kicad_sch, RAM.kicad_sch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]
2026-04-22 Update TS3021ILT part and more routing
    [Frontend.kicad_sch, TSC_board.kicad_pcb]
2026-04-22 Update schematic, more routing
    Add firmware/TSC_RangeControl.ioc (STM32CubeMX project for STM32C011F4Px). Numerous adjustments to the schematic. Update PCB files.
    [ConnDIN41612.kicad_sch, EthernetPHY.kicad_sch, Frontend.kicad_sch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]
2026-04-23 New range control concept
    [Frontend.kicad_sch, TSC_board.kicad_pcb]
2026-04-24 More routing
    [Frontend.kicad_sch]
2026-04-28 Before DRC
    [Conn.kicad_sch, Frontend.kicad_sch, TSC_board.kicad_sch]
2026-04-30 Finished r0
    [Frontend.kicad_sch, TSC_board.kicad_sch]
2026-05-03 Finishing touches
    [-B_Cu.gbl, -B_Mask.gbs, -B_Paste.gbp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]
2026-08-21 Update dac pwr
    [Frontend.kicad_sch, TSC_board.csv, TSC_board.kicad_pcb]
2026-08-25 DRC fixes
    [TSC_board.kicad_pcb]
2026-08-27 Unify passive values, fix LM4040 DNP value, refresh outputs
    [Frontend.kicad_sch, TSC_board.csv, TSC_board.kicad_pcb]
2026-09-28 Last fixes
    [Conn.kicad_sch, Frontend.kicad_sch, TSC_board.csv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]
2026-09-28 Regenerate interactive BOM, update README status to ready for prototype order
2026-09-28 Fix BOM data: 1k resistor MPN, 1N4148WS diodes, ADuM/DAC7311 orderable part numbers, BOM export settings
    [Conn.kicad_sch, Frontend.kicad_sch, RAM.kicad_sch]
2026-09-28 Regenerate production outputs and gerber zip after BOM field fixes
    [TSC_board.csv]

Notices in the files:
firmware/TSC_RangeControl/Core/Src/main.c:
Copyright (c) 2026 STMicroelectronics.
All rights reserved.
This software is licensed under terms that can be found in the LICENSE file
